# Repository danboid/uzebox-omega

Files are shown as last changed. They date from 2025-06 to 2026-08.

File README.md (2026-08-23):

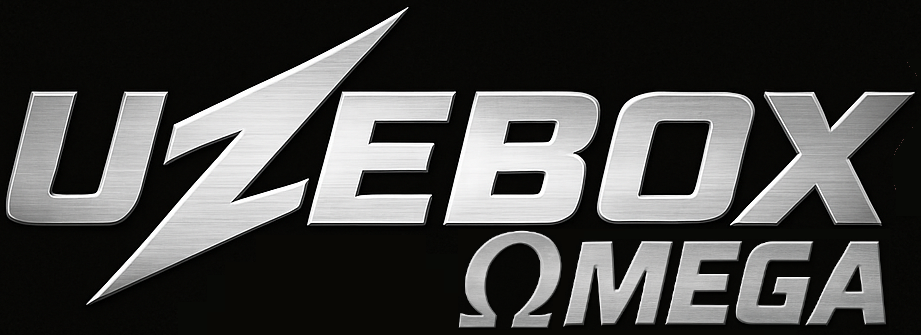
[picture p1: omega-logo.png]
Uzebox Omega logo


The Uzebox Omega is a modified version of the Uzebox open source games console that fits into the official Uzebox case and supports RGB SCART without the need for the expensive AD725 video chip.

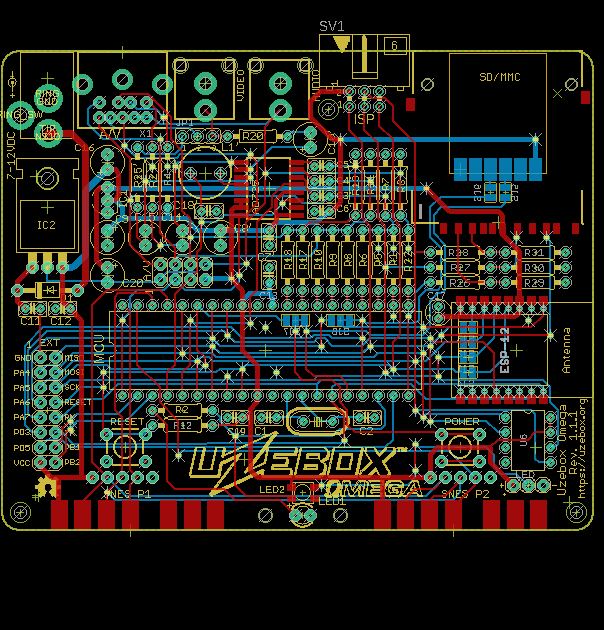
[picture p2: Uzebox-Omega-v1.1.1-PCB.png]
Uzebox Omega PCB


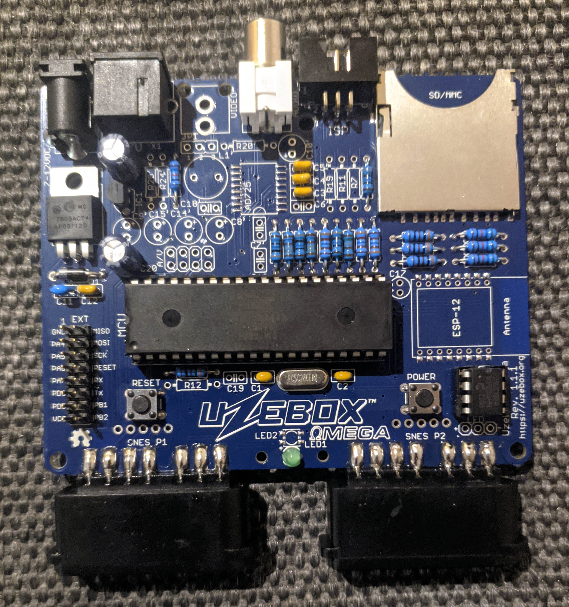
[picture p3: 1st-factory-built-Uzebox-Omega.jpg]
A PCBWay-built Uzebox Omega photo


## What is the same
* General schematic and functions inherited from the Uzebox v1.3.3.
* Mechanical dimensions. All buttons, connectors, holes, etc. are in the same place, so you can use the original case.

## New features
* SCART RGB support. Because space is too limited for the giant SCART connector, we use a Sega Mega Drive 2 compatible 9 pin Mini DIN connector and cables.

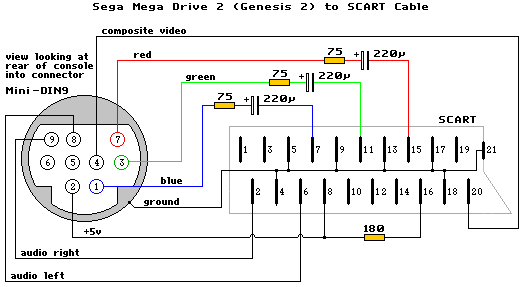
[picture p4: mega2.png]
Mini Din 9 pinout


* The AD725 chip and its surrounding parts are optional now. If you don't populate them RGB video works but you cannot use the composite video RCA jack.
* Optional footprint for an USB to serial module on the bottom side below the SD card socket. You can use this as a power supply connector to power your Uzebox from a USB wall plug. Also you can use it for debug messages, it is connected to the second UART of the AVR CPU. This leads to some small incompatibilities, so you have to activate it by a couple of solder jumpers on the bottom side. See instructions below.
* You can use an WS2812 "Neopixel" LED instead of the normal LED. There is no Uzebox kernel software for this yet. It uses the same pin as the original LED. A connector for adding more WS2812 LEDs is present so maybe you can create a colourful Uzebox sign in the top of your case?
* Added mounting holes for the lightpipe. You can screw or tie it to the board instead of glueing.
* I overworked all the traces to use a cleaner layout.
* The ESP12 WiFi chip can be connected to the CPU's SPI and reset lines. With this it should be possible to flash the AVR MCU via WiFi but we would need a custom Uzenet/ESP8266 firmware to enable this.

## SVideo adapter
The SVideo signals are routed to unused pins 5 (LUMA) and 6 (CHROMA) of the mini DIN socket so it should be possible to create a 9 pin mini DIN to SVideo adapter or cable.
 
## Instructions for using the ESP's SPI connection
The ESP's SPI pins GPIO12, 13 and 14 can be connected to the SPI lines of the AVR CPU so you have a very fast communication line between the two CPUs. GPIO16 can also be connected to the reset of the AVR. It should be possible to flash the AVR from the ESP with this. Four solder jumpers on the bottom of the PCB under the ESP would need to be bridged to enable this.

## Instructions for using the USB to serial module
WARNING: You have to leave out the 5V regulator if you want to use USB as power source!!!

The module has to be soldered to the bottom side of the PCB under the SD card socket. Because we cannot use holes there as they would conflict with the SD card, you have to solder the module directly onto the pads, or solder some angled pin hedaers onto the pad and put the module onto these. This method is perferred because it gives you a bit of distance between the SD card and the USB socket.

There are two solder jumpers near the module. They are open by default. So the module is connected to nothing, only to 5V for power supply.
If you close these jumpers the serial lines of the module will be connected to the second serial port of the AVR CPU. Because these are used by the standard Uzebox power button and ESP_RST pin there are two solder jumper which may connect these to PA5 and PA6 instead. This would need a software modification for software that uses the power button or the ESP_RST pin.

These jumpers are connected by a small wire in compatibility position. Without cutting these lines everything is like the original Uzebox.

## Instructions for WS2812 LED
If you want a colourful Neopixel LED instead of the normal one, just solder a WS2812 mini LED instead of the normal one. You can also skip the LEDs resistor then. There is a 3-pin connector at the right side of the PCB to connect more LEDs but don't overload the power supply!
Keep in mind that controlling such LEDs requires precise timing so it might be tricky to control such LEDs during video output.

## To find out more, please check out the project's sites:
* [Uzebox Omega PCBWay Shared Project](https://www.pcbway.com/project/shareproject/Uzebox_Omega_games_console_77d0d74a.html): Buy a pre-assembled Uzebox Omega from PCBWay.
* [Uzebox Omega Assembly Guide](https://github.com/danboid/uzebox-omega/blob/main/schematics/Uzebox-Omega/V1.1.1/Uzebox-Omega-V1.1.1-assembly-guide.md): How to build a Uzebox Omega. [PDF version for printing.](https://github.com/danboid/uzebox-omega/blob/main/schematics/Uzebox-Omega/V1.1.1/Uzebox-Omega-V1.1.1-assembly-guide.pdf)
* [Uzebox Omega Wiki page](https://uzebox.org/wiki/Omega): Uzebox Omega wiki page including build instructions, revision history etc.
* [Getting started](https://uzebox.org/wiki/Getting_Started_on_the_Uzebox): How to install the toolchains, IDEs and build the codebase. Then move on to tutorials and the rest of the documentation.  
* [Main website](https://uzebox.org): The main hub with news, links, downloads and more.
* [Forums](https://uzebox.org/forums): Share your new game and discuss everything Uzebox.
* [Wiki](https://uzebox.org/wiki): All of the Uzebox project's documentation.

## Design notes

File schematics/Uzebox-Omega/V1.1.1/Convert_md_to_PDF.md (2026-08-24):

# Converting markdown (.md) to PDF

I found that the markdown version of the assembly guide did not print well under most browsers.

I converted the markdown assembly guide into a PDF under Debian using these commands:

```
sudo apt install pandoc weasyprint
cd uzebox-omega/schematics/Uzebox-Omega/V1.1.1
pandoc Uzebox-Omega-V1.1.1-assembly-guide.md -o Uzebox-Omega-V1.1.1-assembly-guide.pdf --pdf-engine=weasyprint --css=style.css
```

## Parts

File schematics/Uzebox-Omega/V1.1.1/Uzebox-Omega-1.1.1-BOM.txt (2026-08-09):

Uzebox Omega v1.1.1 BOM - based upon the BOM of Uzebox v1.3.3. Last updated 9th August 2026.

Parts sourced from Digikey. Farnell equivalent order codes are listed in square brackets.

-----------------------------------------------------------------------------------------

1   2092-KMDGX-9S-BS-1-ND       CONN RCPT FMALE MINI DIN 9P SLDR    (X1) [152392] or use MDC-209

1   CP-1420-ND                  CONN RCA JACK R/A WHITE PCB         (AUDIO) [1280699] or [4066359] - Farnell only sell audio jacks for Omega v1.2+

1   CP-002A-ND                  CONN POWER JACK 2.1MM               (U5) [3498419] or [2839850]

1   2057-BHR-06-HUA-ND          CONN HEADER R/A 6POS 2.54MM         (ISP) [2751306]

1   10129381-916001BLF-ND       CONN HEADER VERT 16POS 2.54MM       (EXT) [1593445]

1   3M5471-ND                   SOCKET IC OPEN FRAME 40POS .6"      [2453477]

2   TS02-66-43-BK-100-LCR-D     6MM LIGHT TOUCH SWITCH 100GF        (POWER,RESET) [2543101]

1   732-3816-1-ND               CONN SD CARD PUSH-PUSH R/A SMD      (SD/MMC) [2081359]

2   399-9718-ND                 CAP CER 18PF 100V 5% NP0 RADIAL     (C1,C2) [3001200] or [2332948]

2   399-ESK105M350AE3AA-ND      CAP ELECT 1UF 50V VR RADIAL         (C16,C20) [9451358]

4   478-3192-ND                 CAP CER .10UF 50V 20% RADIAL        (C3,C4,C5,C12) [3289388]

1   478-5733-ND                 CAP CER .33UF 50V Z5U 20% RADIAL    (C11) [4143699]

4   301XBK-ND                   RES 301 OHM 1/4W 1% METAL FILM      (R2,R26,R27,R28) [9467149] or [1083195]

4   562XBK-ND                   RES 562 OHM 1/4W 1% METAL FILM      (R29,R30,R31,video fix) [4141008] or [9502386]

3   3.16KXBK-ND                 RES 3.16K OHM 1/4W 1% METAL FILM    (R1,R8,R22) [1083307]

1   13-MFR-25FTE52-180RCT-ND    RES 180 OHM 1% 1/4W 1% METAL FILM   (R4) [1083165] *

3   1.58KXBK-ND                 RES 1.58K OHM 1/4W 1% METAL FILM    (R5,R9,R17) [9465375] or [9500928]

4   806XBK-ND                   RES 806 OHM 1/4W 1% METAL FILM      (R3,R6,R10,R18) [9470204] or [1751433]

1   ATMEGA644A-PU               IC MCU AVR 64K FLASH 40-DIP         (MCU) [1288340]

1   MC7805ACTGOS-ND             IC REG LINEAR 5V 1A TO220           (IC2) [9664505]

1   641-1310-1-ND               1N4001 DIODE RECTIFIER 1A 50V DO-41 (D1) [2822512]

1   XC1728-ND                   CRYSTAL 28.63636MHZ 18PF TH         (XTAL) [1842243]

1   MCP1700-3302E/TO-ND         IC LDO REG 250MA 3.3V TO-92-3       (IC1) [1331485] or [1296588]

1   67-1056-ND                  LED 3MM SHORT LENS GREEN DIFF       (LED1) [L034XGT] or [3780477] for a brighter LED

--Optional parts for Uzebox Omega composite or svideo (via adapter) video output (UNTESTED)--

1   AD725ARZ-ND                 IC ENCODER RGB TO NTSC 16-SOIC      (U2) See alternative source below.

1   CP-1421-ND                  CONN RCA JACK R/A YELLOW PCB        (VIDEO)

2   478-3192-ND                 CAP CER .10UF 50V 20% RADIAL        (C6,C7)

2   P19607CT-ND                 CAP ALUM 10UF 20% 50V RADIAL        (C8,C9)

1   493-1041-ND                 CAP 220UF 16V ELECT VR RADIAL       (C10)

1   P19607CT-ND                 CAP ALUM 10UF 20% 50V RADIAL        (C13) [2841905]

2   493-1041-ND                 CAP 220UF 16V ELECT VR RADIAL       (C14,C15) [8767149]

3   75.0XBK-ND                  RES 75.0 OHM 1/4W 1% METAL FILM     (R20,R24,R25) [1127008]

1   399-9718-ND                 CAP CER 18PF 100V 5% NP0 RADIAL     (C18)

1   RLB0914-680KL-ND            INDUCTOR 68UH 10% RADIAL            (L1)

1   SAM1112-03-ND               CONN HEADER VERT 3POS 2.54MM        (JP1) [1593412]

1   S9337-ND                    CONN JUMPER SHORTING .100" GOLD     (JP1) [2834673]

--Optional SPI RAM module--     Required by UzeboxPC, UzeMOD etc.

1   23LC1024-I/P-ND             IC SRAM 1MBIT SPI/QUAD 8DIP         (U6, not available from Farnell)

1   AE9986-ND                   CONN IC DIP SOCKET 8POS TIN         (U6) [2678577]

--Optional Uzenet Interface--   Requires the SPI RAM module components

1   https://vi.aliexpress.com/item/32264795859.html                 ESP-12F WiFi Module. Not available from Farnell. DigiKey uses non compat. firmware

1   445-8417-ND                 CAP CER 1UF 16V X7R RADIAL          (C17)

2   2057-2RS1-08-G-ND           RECEPTACLE STRIP 8P 2.0MM PITCH     (ESP12)

2   952-2278-ND                 CONN HEADER VERT 8POS 2MM           (To solder onto ESP-12F WiFi module)

--Optional Uzebox parts--

1   993-PYA15T120125-ND         AC/DC WALL MOUNT ADAPTER 12V 15W      12V 15 W AC/DC External Wall Mount Adapter Multi-Blade (Included) Input. US/EU/UK/AU plugs.

1   102-6551-ND                 AC/DC WALL MOUNT ADAPTER 12V 6W       12V 6 W AC/DC External Wall Mount PSU. Includes North American, Europe, UK, Australia and China plugs.

1   1470-VFR05US090-JA-ND       9V 5W AC/DC External Wall Mount (Class II) Adapter Multi-blade (plugs) included - US, UK, EU and AU.

1   364-1253-ND                 9V 6W 600ma DC wall mount, Positive Center, Barrel Plug, 2.1mm I.D. x 5.5mm O.D. x 9.5mm, North American plug only.

1   3373676                     MicroSD Memory Card Connector       Can only be used instead of the full sized SD on Uzebox Omega 1.3+.

4   SJ5303-7-ND                 BUMPON HEMISPHERE .44X.20 CLEAR

Parts sourced elsewhere

------------------------------------------------------------------------------------

1   PRT-12769               SD/MMC Socket (Alternate source)        (SD/MMC)                        https://www.sparkfun.com/products/12769

1   AD725ARZ                IC ENCODER RGB TO NTSC 16-SOIC (alternate, much cheaper source) (U2)    https://vi.aliexpress.com/item/33022801012.html . AD725 is not recommended for the Omega.

2   SNES connectors         (Straight pin version) AliExpress.com   (SNESP1,SNESP2)                 Prefered, 180 degree model: https://www.aliexpress.com/item/32879502446.html , alternative 90 degree connector: https://vi.aliexpress.com/item/32838396935.html

1   PCB                     JLCPCB.com PCB Manufacturing service                                    See the following on how to order: https://uzebox.org/forums/viewtopic.php?p=33217#p33217 or use PCBWay.com

2   SNES controllers        SNES/SFC Controller Classic Wired Gamepad                               https://vi.aliexpress.com/item/1005007109314003.html

1   SCART AV cable          RGB Scart cable for Sega Mega Drive 2                                   https://vi.aliexpress.com/item/1005007039881314.html , see https://uzebox.org/wiki/Uzebox_SCART_Interface#SCART_cables for more

1   AVR programmer          USBASP USBISP AVR Programmer                                            https://www.aliexpress.com/item/32670511994.html , be sure to buy one with 10 pin to 6 pin cable adapter

* For R4, this BOM currently uses a 180 Ohm resistor from Digikey but a 162 Ohm resistor from Farnell, because Farnell UK currently only sell 180 Ohm resistors in batches of 10 or more. Any resistor from 150 to around 220 Ohms should suffice for R4.

https://uzebox.org/wiki/Omega

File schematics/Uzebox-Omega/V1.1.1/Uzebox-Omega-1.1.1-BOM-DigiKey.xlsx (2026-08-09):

Digi-Key Part Number | Quantity | Uzebox Omega v1.1.1 Digi-Key BOM. Last updated 9th August 2026.
2092-KMDGX-9S-BS-1-ND | 1 | CONN RCPT FMALE MINI DIN 9P SLDR (X1)
CP-002A-ND | 1 | CONN POWER JACK 2.1MM (7-12VDC)
CP-1420-ND | 1 | CONN RCA JACK R/A WHITE PCB (AUDIO)
2057-BHR-06-HUA-ND | 1 | CONN HEADER R/A 6POS 2.54MM (ISP) or 75867-231LF-ND
10129381-916001BLF-ND | 1 | CONN HEADER VERT 16POS 2.54MM (EXT)
3M5471-ND | 1 | SOCKET IC OPEN FRAME 40POS .6" (MCU)
TS02-66-43-BK-100-LCR-D | 2 | 6MM LIGHT TOUCH SWITCH 100GF (POWER,RESET)
732-3816-1-ND | 1 | CONN SD CARD PUSH-PUSH R/A SMD (SD/MMC)
399-9718-ND | 2 | CAP CER 18PF 100V 5% NP0 RADIAL (C1,C2)
399-ESK105M350AE3AA-ND | 2 | CAP ALUM 1UF 20% 350V RADIAL TH (C16,C20)
478-3192-ND | 4 | CAP CER .10UF 50V 20% RADIAL (C3,C4,C5,C12)
478-5733-ND | 1 | CAP CER .33UF 50V Z5U 20% RADIAL (C11)
301XBK-ND | 4 | RES 301 OHM 1/4W 1% METAL FILM (R2,R26,R27,R28)
562XBK-ND | 4 | RES 562 OHM 1/4W 1% METAL FILM (R29,R30,R31) and X1 video fix
3.16KXBK-ND | 3 | RES 3.16K OHM 1/4W 1% METAL FILM (R1,R8,R22)
13-MFR-25FBF52-162R-ND | 1 | RES 162 OHM 1% 1/4W AXIAL (R4)
1.58KXBK-ND | 3 | RES 1.58K OHM 1/4W 1% METAL FILM (R5,R9,R17)
806XBK-ND | 4 | RES 806 OHM 1/4W 1% METAL FILM (R3,R6,R10,R18)
ATMEGA644A-PU | 1 | IC MCU AVR 64K FLASH 40-DIP (MCU)
MC7805ACTGOS-ND | 1 | IC REG LINEAR 5V 1A TO220 (IC2)
641-1310-1-ND | 1 | 1N4001 DIODE RECTIFIER 1A 50V DO-41 (D1)
XC1728-ND | 1 | CRYSTAL 28.63636MHZ 18PF TH (XTAL)
MCP1700-3302E/TO-ND | 1 | IC LDO REG 250MA 3.3V TO-92-3 (IC1)
67-1056-ND | 1 | LED 3MM SHORT LENS GREEN DIFF (LED1)
AE9986-ND | 1 | CONN IC DIP SOCKET 8POS TIN (U6) - optional but recommended
23LC1024-I/P-ND | 1 | IC SRAM 1MBIT SPI/QUAD 8DIP (U6) - optional but recommended

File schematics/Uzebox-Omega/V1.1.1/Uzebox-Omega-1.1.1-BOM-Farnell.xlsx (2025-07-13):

Part Number | Quantity | Uzebox Omega v1.1.1 Farnell components BOM. Last updated 12th July 2025.
152392 | 1 | 9-pole Mini DIN Audio/Video Socket
3498419 | 1 | DC Power Connector, Receptacle, 2.1 mm, PCB Mount, Solder or use 2839850
2751306 | 1 | Pin Header, Right Angle, Wire-to-Board, 2.54 mm, 2 Rows, 6 Contacts, Through Hole Right Angle or 2215288
1593445 | 1 | MULTICOMP PRO 2213S-16GPin Header, Board-to-Board, 2.54 mm, 2 Rows, 16 Contacts, Through Hole Straight, 2213S
2453477 | 1 | IC & Component Socket, 40 Contacts, DIP Socket, 2.54 mm, 15.24 mm, Phosphor Bronze
2543101 | 2 | Tactile Switch, MCDTS-6, Top Actuated, Through Hole, Round Button, 160 gf, 50mA at 12VDC
2081359 | 1 | Memory Card Connector, SD, Push-Push, 9 Contacts, Copper, Gold Plated Contacts, WR-CRD
3001200 | 5 | Multilayer Ceramic Capacitor, 18 pF, 100 V, ± 5%, Radial Leaded, C0G / NP0, 2.5 mm. Only 2x needed, 5x min sale or use 2332948
9451358 | 2 | MULTICOMP PRO MCGPR50V105M5X11Electrolytic Capacitor, 1 µF, 50 V, ± 20%, Radial Leaded, 2000 hours @ 85°C, Polar
3289388 | 4 | Multilayer Ceramic Capacitor, 0.1 µF, 50 V, ± 10%, Radial Leaded, X7R, 2.5 mm
4143699 | 1 | Multilayer Ceramic Capacitor, 0.33 µF, 50 V, ± 10%, PC Pin, X7R, 2.5 mm
9467149 | 10 | Through Hole Resistor, 301 ohm, MRS25 Series, 600 mW, ± 1%, Axial Leaded, 350 V. Only 4x needed, 10x min sale or use 1083195
4141008 | 10 | Through Hole Resistor, 562 ohm, MBB0207 Series, 600 mW, ± 1%, Axial Leaded, 350 V. Only 3x needed, 10x min sale or use 9502386
1083307 | 3 | Through Hole Resistor, 3.16 kohm, R, 250 mW, ± 0.1%, Axial Leaded, 500 V
1083165 | 1 | Through Hole Resistor, 162 ohm, R, 250 mW, ± 0.1%, Axial Leaded, 500 V
9465375 | 10 | Through Hole Resistor, 1.58 kohm, MRS25, 600 mW, ± 1%, Axial Leaded, 350 V. Only 3x needed, 10x min sale or use 9500928 .
9470204 | 10 | Through Hole Resistor, 806 ohm, MRS25, 600 mW, ± 1%, Axial Leaded, 350 V. Only 4x needed or use 1751433
1288340 | 1 | 8 Bit MCU, Low Power High Performance, AVR ATmega Family ATmega64 Series Microcontrollers, AVR
9664505 | 1 | Linear Voltage Regulator, 7805, Fixed, Positive, 10V To 35V In, 5V And 1A Out, TO-220-3
2822512 | 5 | Standard Recovery Diode, 50 V, 1 A, Single, 1.1 V, 30 A. Only 1x needed, 5x min sale
1842243 | 1 | Crystal, 28.63636 MHz, Through Hole, 11.5mm x 5mm, 10 ppm, 18 pF, 10 ppm, 9B
1331485 | 1 | MICROCHIP MCP1702-3302E/TO, Fixed LDO Voltage Regulator, 2.7V to 13.2V, 525mV Dropout, 3.3Vout, 250mAout, TO-92-3 or use 1296588
L034XGT | 5 | MULTICOMP PRO L034XGTLED, AlInGaP, Green, Through Hole, T-1 (3mm), 20 mA, 2.1 V, 570 nm. Only 1x needed, 5x minimum sale or use 3780477 if you want a brighter power LED.

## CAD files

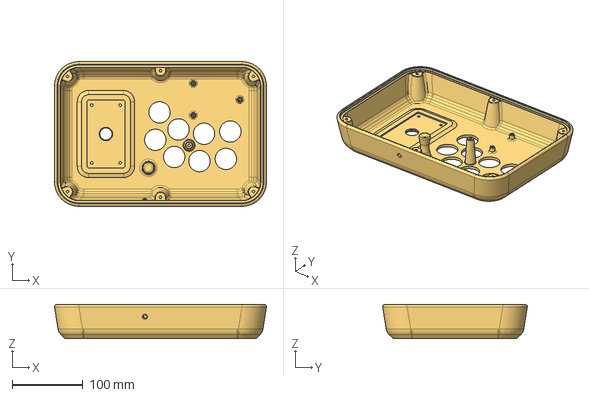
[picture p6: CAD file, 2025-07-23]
cad/Enclosures/fightstick/Fight Stick Uzebox Edition v7.step
299.2 x 204.2 x 48.0 mm

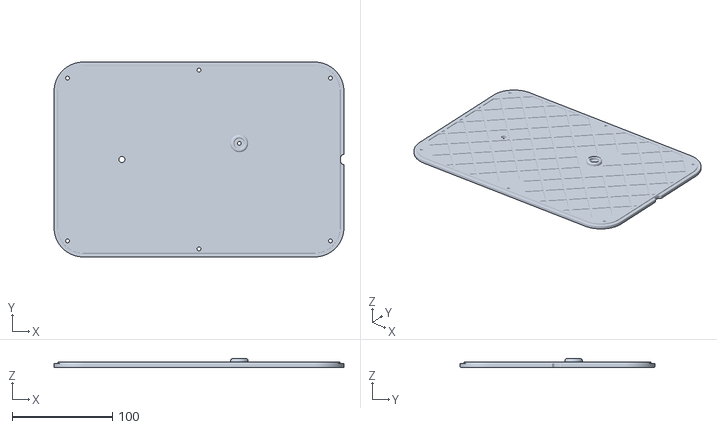
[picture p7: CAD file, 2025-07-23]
cad/Enclosures/fightstick/Fightstick Bottom V3 30mm.stl
289.6 x 194.6 x 8.70

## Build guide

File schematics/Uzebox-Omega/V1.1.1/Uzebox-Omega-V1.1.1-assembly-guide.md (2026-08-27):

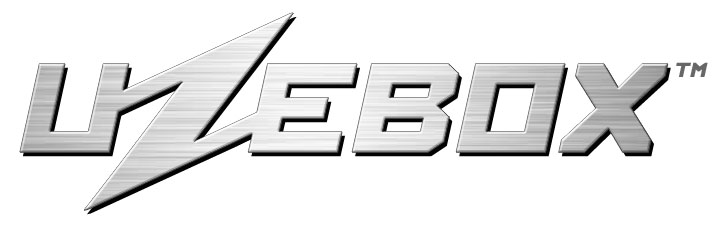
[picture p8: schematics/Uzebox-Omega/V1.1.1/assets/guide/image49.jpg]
Uzebox V5.0


# Uzebox Omega assembly guide
For Uzebox Omega Revision V1.1 to v1.4

> [!NOTE]  
> This assembly guide was written with consideration of the electronics beginner who only has a minimal set of tools. Some of the methods described in this guide are makeshift solutions for those without more professional tooling. Use the method which works best for you.

## Revision History
| Version | Date | Author | Description |
| :---- | :---- | :---- | :---- |
| 0 | 01-Nov-2012 | A.Bourque | Initial release |
| 1 | 6-Nov-2012 | A.Bourque | Minor corrections |
| 2 | 28-Jan-2014 | A.Bourque | Minor changes |
| 3 | 27-Jan-2015 | A.Bourque | Added replacement parts for EXT header and SD card socket |
| 4 | 21-Feb-2015 | A.Bourque | Added preliminary troubleshooting section |
| 5 | 26-Nov-2015 | A.Bourque | Minor improvements |
| 6 | 1-Feb-2016 | A.Bourque | Added note regarding power button |
| 7 | 15-Nov-2016 | A.Bourque | Added notes for PCB rev 1.3.1 and references to the Uzenet interface. |
| 8 | 13-Aug-2024 | A.Bourque | Ported the assembly guide to GitHub and added minor improvements. |
| 9 | 28-Aug-2024 | D.MacDonald | Several additions and improvements. |
| 10 | 17-Sep-2024 | D.MacDonald | Add solder flux, a video cable and a SNES controller to the "Other parts required" table. |
| 11 | 11-Jul-2025 | D.MacDonald | Started work on modifying the Uzebox assembly guide for the Uzebox Omega. |

## Parts list verification
> [!IMPORTANT]  
> Ensure you have all the required parts before starting, 

<!--
> [!TIP] 
> Click on the images for a bigger view.
-->
| Component Image | Schematic Reference | Description |
| ----- | ----- | ----- |
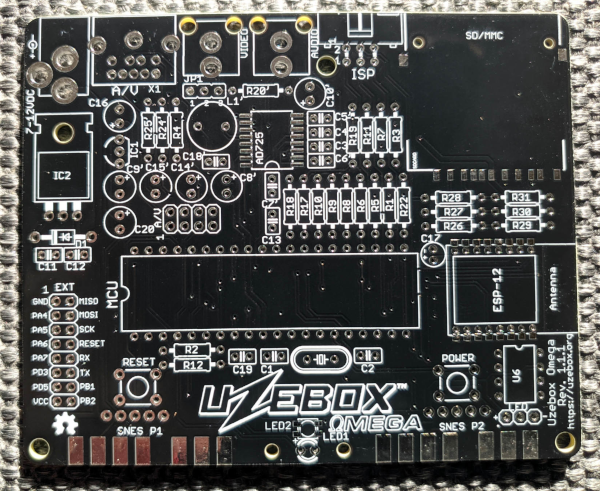
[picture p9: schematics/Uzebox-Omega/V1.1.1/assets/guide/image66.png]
Uzebox Omega PCB
|  | N/A 		 | Uzebox Omega printed circuit board (PCB) 		 |
| Power Jack | N/A 		 | DC power jack 		 |		 		 |
| Audio RCA Jack | AUDIO 		 | Audio output RCA jack (Red or white) - optional		 |
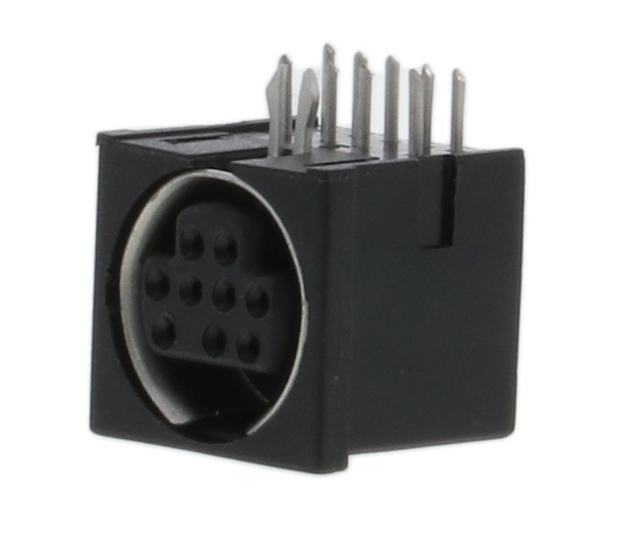
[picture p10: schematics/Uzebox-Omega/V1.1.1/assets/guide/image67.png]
Mini DIN RGB SCART AV output
|  | X1 		 | A female, 9 pin mini DIN socket 			 		 |
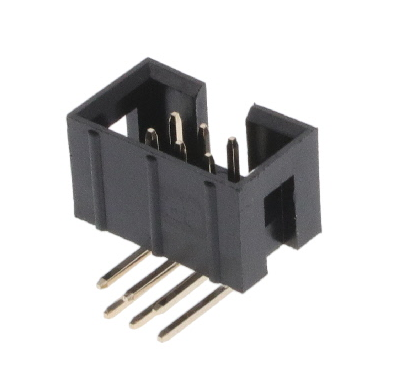
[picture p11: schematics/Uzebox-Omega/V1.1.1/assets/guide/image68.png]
Right-angled ISP programming port
|  | ISP 		 | Right-angled Atmega644 programming ports are preferred over vertical ones. 					 		 |
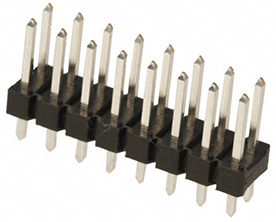
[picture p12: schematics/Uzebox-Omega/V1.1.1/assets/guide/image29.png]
Extension Header
|  | EXT 		 | Extension port header - optional		 |
| DIP-40 Socket  | MCU 	 | DIP-40 socket for the Atmega644 							 |
| Tactile Switches  | POWER / RESET  | Tactile 	switches (x2) 				 |
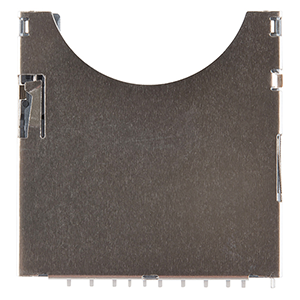
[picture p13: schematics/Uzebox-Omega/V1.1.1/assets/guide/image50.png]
SD Card Socket
|   | SD/MMC 		 | Secure Digital memory card socket. One of the two possible models has a soldering wing on the right side only. |
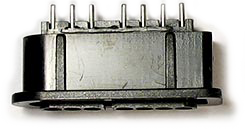
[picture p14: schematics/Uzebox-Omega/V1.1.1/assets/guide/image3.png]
SNES Connector
|   | SNESP1 SNESP2 	 		 | SNES gamepad connectors (x2)			 		 |
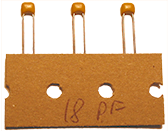
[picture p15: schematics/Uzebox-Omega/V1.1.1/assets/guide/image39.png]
18pF Capacitors
|   | C1,C2 		 | 18pF ceramic capacitors		 		 |
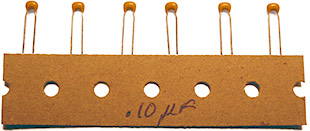
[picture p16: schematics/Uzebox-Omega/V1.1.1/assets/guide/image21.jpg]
100nF Capacitors
|   | C3,C4,C5, C12 	 | .10uF (100nF) ceramic capacitors 	 |
| .33uF Capactitor  | C11 | .33uF (330nF) ceramic capacitor 	 |		 |		 |
| 301 Ohm Resistor  | R2,R26, R27,R28  | Resistor 301Ω 1% (Orange, black, brown, black, brown) 		 |
| 560 Ohm Resistor  | R29,R30, R31, video fix | Resistor 562Ω 1% (Green, blue, red, black, brown) 	 |
| 806 Ohm Resistor  | R3,R6,R10,R18 		 | Resistor 806Ω 1% (Gray, black, blue, black, brown)	 |
| 1.58K Ohm Resistor  | R5,R9,R17	 | Resistor 1.58KΩ 1% (Brown, green, gray, brown, brown)  |
| 3.16K Ohm Resitor  | R1,R8,R22	 | Resistor 3.16KΩ 1% (Orange, brown, blue, brown, brown) 	 |
| Atmega644 Microcontroller  | MCU 	 | ATmega644 microcontroller 			 		 |
| Crystal  | XTAL | 28.63636Mhz crystal  |			 		 |
| 3.3V Voltage Regulator  | IC1 	 | 3.3V voltage regulator  |
| 5V Voltage Regulator  | IC2 	 | 5.0V voltage regulator 		 |
| Rectifier Diode  | D1  | Rectifier diode 			 |
| LED  | LED1	 | Power	LED  |
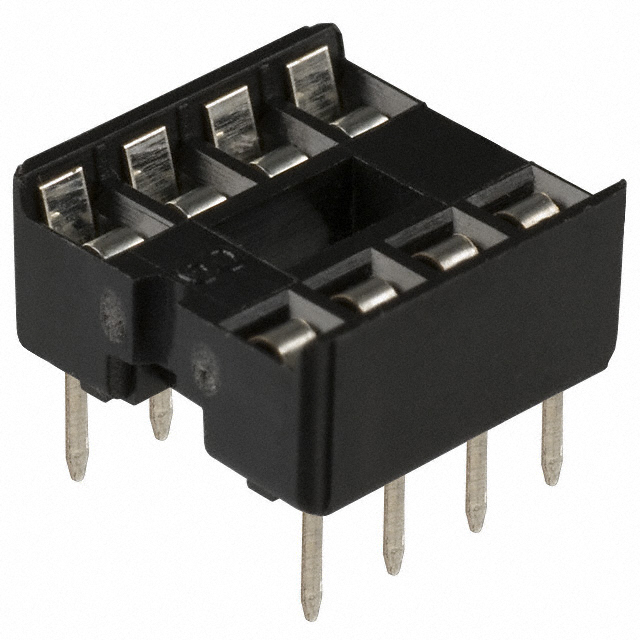
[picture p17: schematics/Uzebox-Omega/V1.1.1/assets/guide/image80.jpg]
DIP-8 Socket
|   | U6	 | SPI SRAM socket - optional |
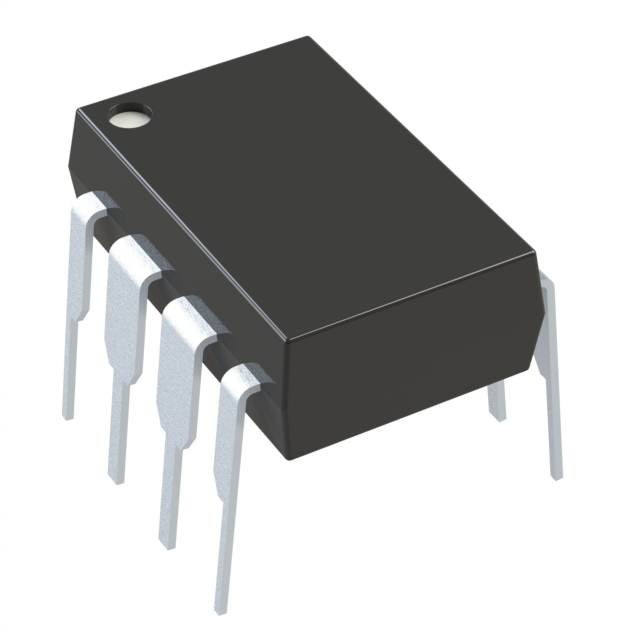
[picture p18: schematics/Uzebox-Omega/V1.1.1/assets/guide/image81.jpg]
1Mb SPI SRAM
|   | U6	 | 1Mb (128KB) SPI SRAM IC - optional |

## Tools required

To assemble this kit you will need the following tools:

| Tool | Description |
| :---: | ----- |
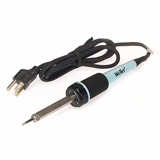
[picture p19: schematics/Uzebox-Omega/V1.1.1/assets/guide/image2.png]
Soldring Iron
|  | A basic soldering iron, 25W-40W. |
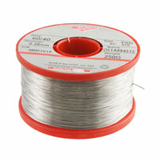
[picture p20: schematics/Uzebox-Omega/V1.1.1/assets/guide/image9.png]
Solder
|   | Solder, rosin core, 60/40 type. |
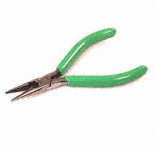
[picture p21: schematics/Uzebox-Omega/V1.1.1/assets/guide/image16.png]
Long Nose Plyers
|   | Long nose pliers. |
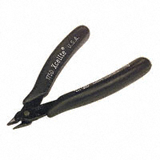
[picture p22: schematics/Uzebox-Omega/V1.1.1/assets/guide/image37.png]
Shear Cutters
|   | Regular cutters will do fine, but shear cutters will do a better job. |
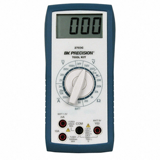
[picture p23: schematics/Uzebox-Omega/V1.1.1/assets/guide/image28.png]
|   | A basic multimeter is not essential but highly recommended for verifications and troubleshooting. |
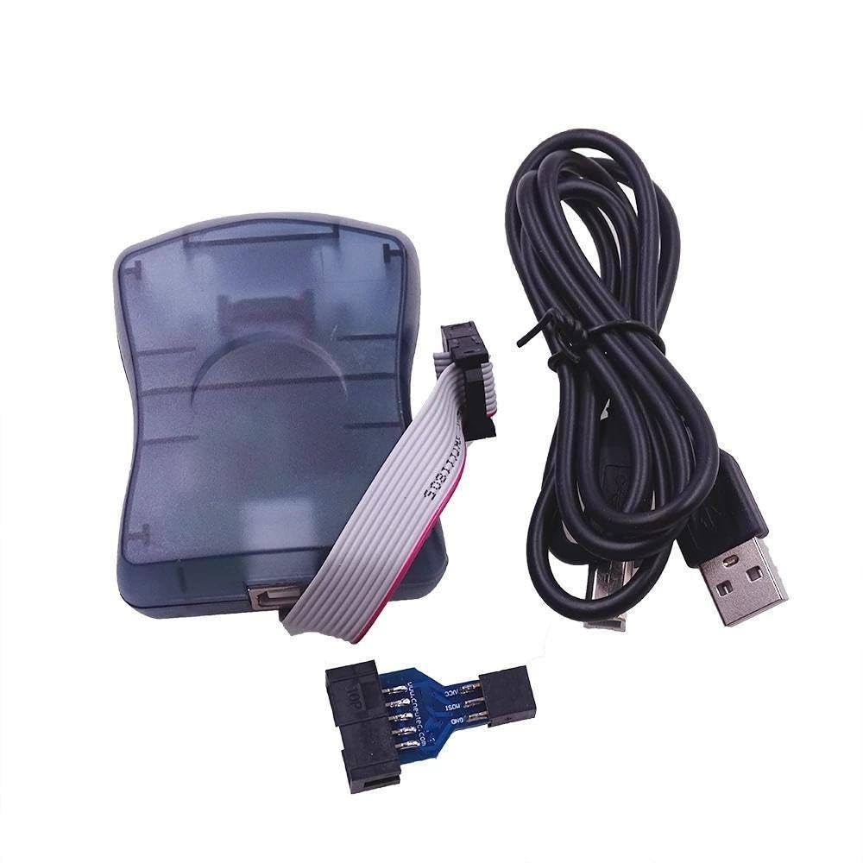
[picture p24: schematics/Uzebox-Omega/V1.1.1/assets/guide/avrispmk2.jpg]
AVRISpmk2
|   | An AVR ISP programmer. Required to flash the Atmega644 microcontroller. Alternately, you can flash the Atmega using [avrdude](https://uzebox.org/wiki/Avrdude) and the GPIO header of a Raspberry Pi or similar.|

## Other parts required

| Part | Description |
| :---: | ----- |
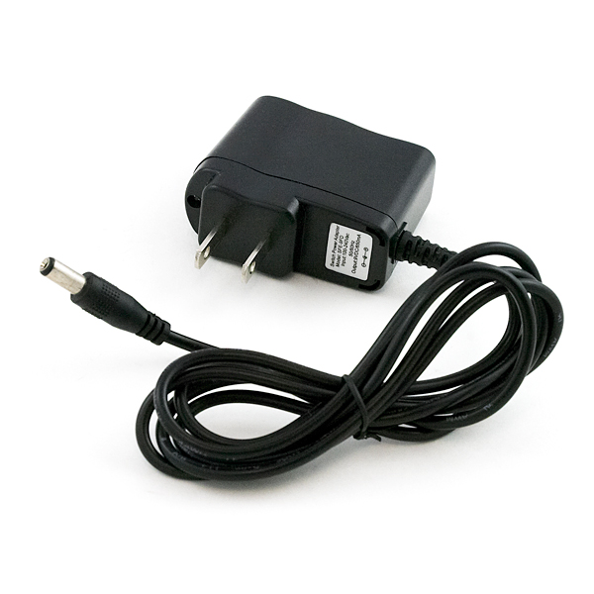
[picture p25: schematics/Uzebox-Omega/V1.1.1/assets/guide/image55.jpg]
Power supply
|   | A standard 7-12VDC barrel connector power supply with a center-positive, 5.5x2.1mm tip. See the Omega's text BOM for a few suitable DigiKey PSUs. |
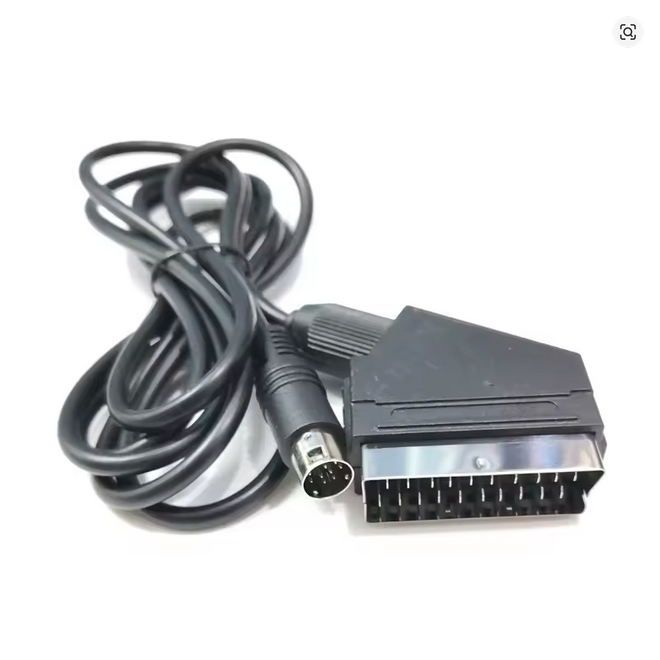
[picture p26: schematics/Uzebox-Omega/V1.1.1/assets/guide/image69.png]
Sega Mega Drive / Genesis 2 RGB SCART cable
|   | A Sega Mega Drive 2 / Sega Genesis 2 compatible 9 pin mini DIN to RGB SCART cable. [Shielded, CSYNC cables](https://uzebox.org/wiki/Uzebox_SCART_Interface#SCART_cables) are recommended for the best sound and video quality. |
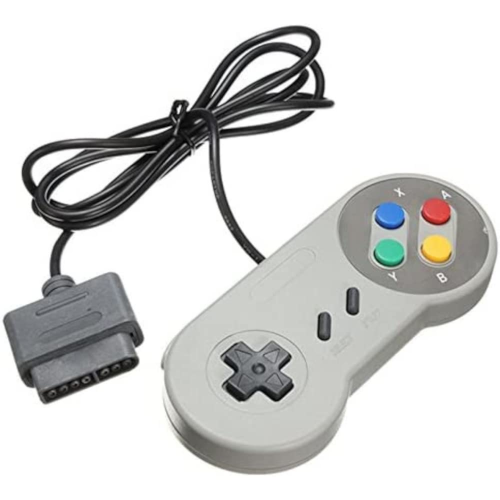
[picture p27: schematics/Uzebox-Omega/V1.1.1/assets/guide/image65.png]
SNES controller
|   | A [SNES controller.](https://uzebox.org/wiki/FAQ#Where_can_I_buy_Uzebox_compatible_controllers?) |
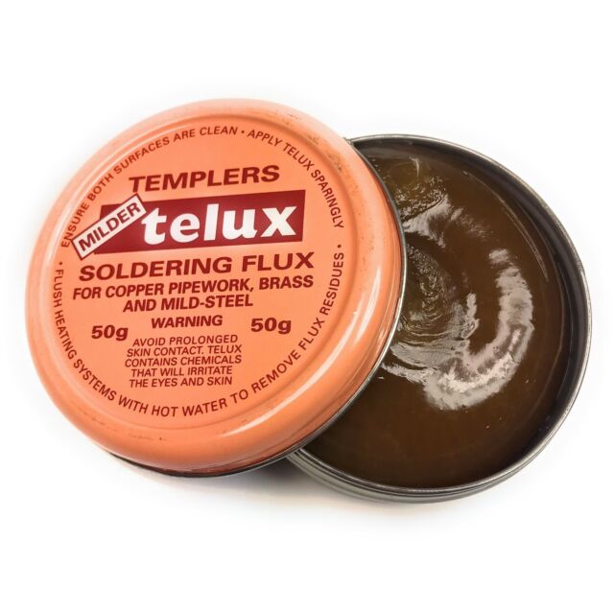
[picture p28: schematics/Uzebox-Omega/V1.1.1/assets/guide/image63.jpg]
Solder flux
|   | Solder flux. Not strictly required but flux makes it much easier to solder the SNES connectors and SD card socket.|

## Building the kit
### Assembling the power supply section

<table>
    <tr>
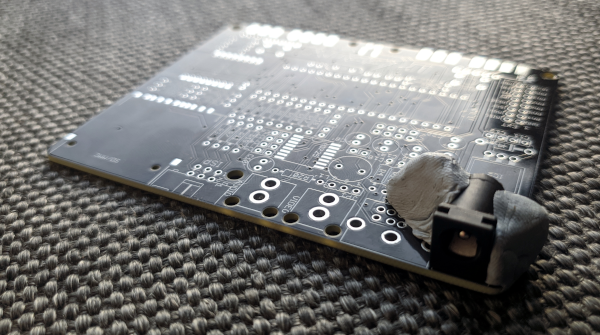
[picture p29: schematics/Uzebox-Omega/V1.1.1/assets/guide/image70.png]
        <td width="50%"></td>
        <td>If your power jack is too far out of alignment it can prevent you correctly inserting the mini DIN AV socket. I use Blu Tack or some other putty-like adhesive to keep the power jack correctly aligned whilst soldering it.</td>
    </tr>
    <tr>
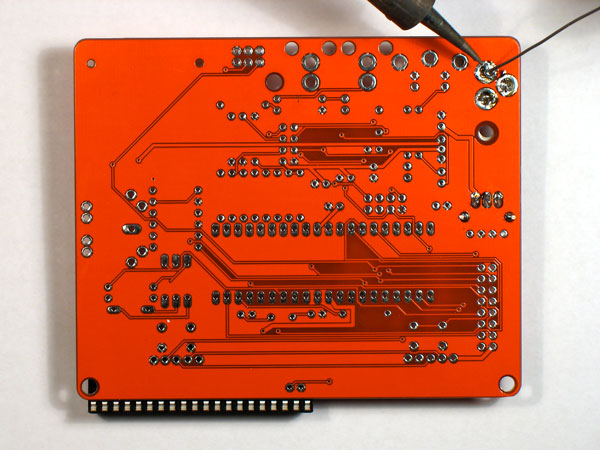
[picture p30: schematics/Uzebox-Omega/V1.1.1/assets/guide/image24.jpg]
        <td></td>
        <td>Insert the DC barrel jack. It is recommended that you start by soldering the power jack first. The main reason being it is quite easy to solder the power jack at an angle with the PCBs that use the circular power jack footprints instead of using slots, as used on later revisions of the Omega. The power jack can be tricky to desolder if you don't own a desoldering station/gun so if you mess up by not soldering the power jack on straight enough then you may as well start over with a new PCB if you don't own any desoldering tools.<br/><br/>Bend the pins on the soldering side to keep it held firmly in place. To ensure it's soldered flat, you can also put the 40 pin DIP socket underneath the PCB to level it up. Be sure to put plenty of solder on the three pins so that the jack is securely mounted.</td>
    </tr>
    <tr>
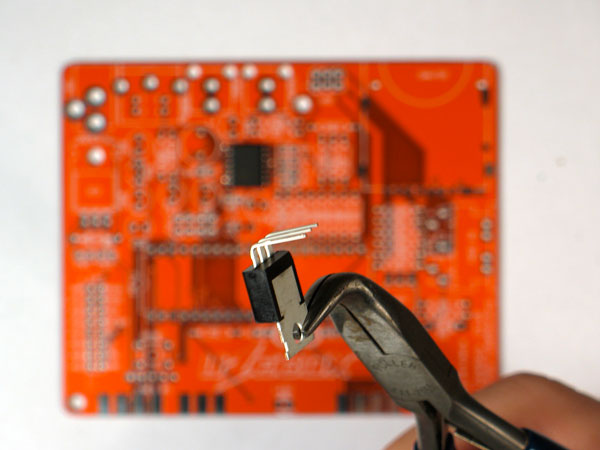
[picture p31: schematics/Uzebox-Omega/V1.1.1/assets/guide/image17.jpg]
        <td width="50%"></td>
        <td>Using pliers, bend the pins of <b>IC2</b>, the 5V voltage regulator, at a 90 degrees angle as pictured. Alternately, insert the legs into the PCB up to the notches then bend the top part until it is lying flat on the PCB. Whilst holding the regulator flat, use the edge of a ruler or maybe a file to bend the regulators legs flat against the PCB on the underside of the board.</td>
    </tr>
    <tr>
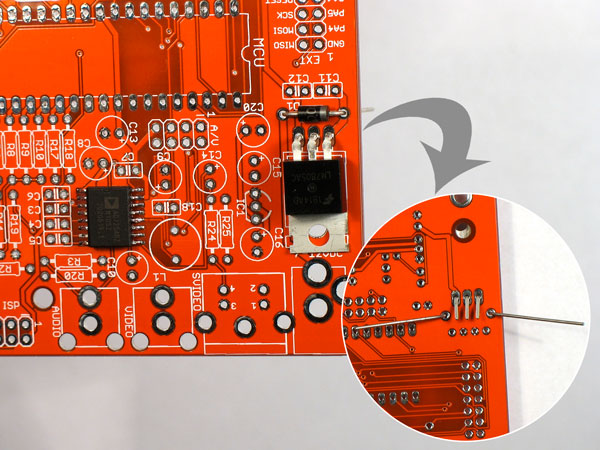
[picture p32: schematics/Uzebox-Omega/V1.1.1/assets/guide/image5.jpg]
        <td></td>
        <td>Mount <b>IC2</b> on the PCB along diode <b>D1</b>. Notice the diode has a white stripe on one end to indicate the direction of current. Ensure the band matches with the component’s drawing on the PCB. As with all future components you will solder, when inserting a component, bend its pins on the other side of the PCB so it holds in place.  Flip the PCB and solder all pins.</td>
    </tr>
    <tr>
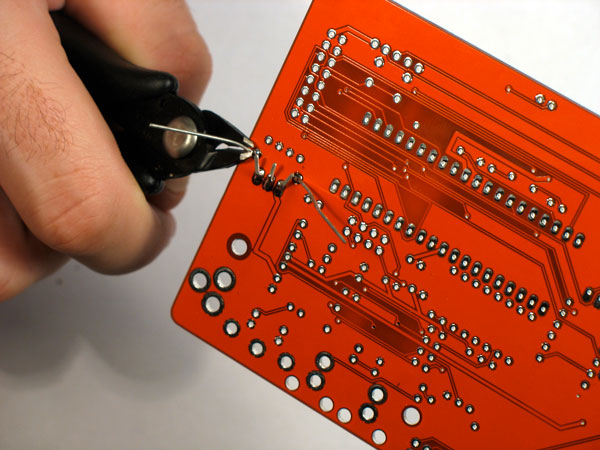
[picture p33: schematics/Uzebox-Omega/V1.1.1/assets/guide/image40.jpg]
        <td></td>
        <td>Using the cutters, cut the pins excess wire. It is recommended that you wear eye protection when using wire cutters. You should hold wires whilst cutting them to stop the wire bits flying into someones eye.</td>
    </tr>
    <tr>
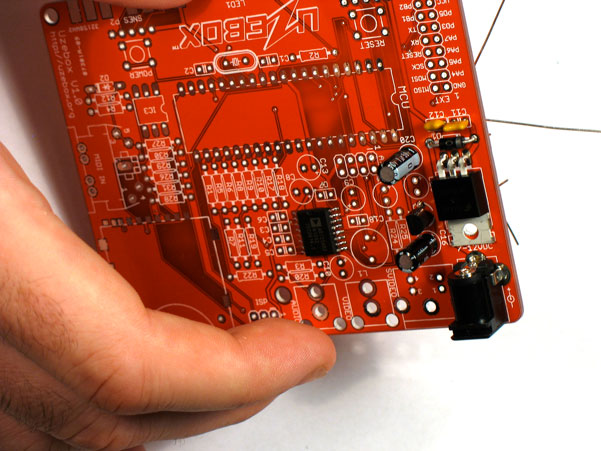
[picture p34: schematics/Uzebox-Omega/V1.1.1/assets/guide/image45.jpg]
        <td></td>
        <td>Add <b>C11</b> (.33uF), <b>C12</b> (100nF), <b>C16</b> (1uF), <b>C20</b> (1uF) and <b>IC1</b> (3.3v regulator). The electrolytic capacitors (the black or dark blue cans) have a polarity. The negative pin is marked with a white stripe and little minus signs on the side. Ensure the opposite pin (the longest one) inserts in the hole which has a little "+" next to it. Solder all pins and remove excess wire. That completes the power supply section.</td>
    </tr>
    <tr>
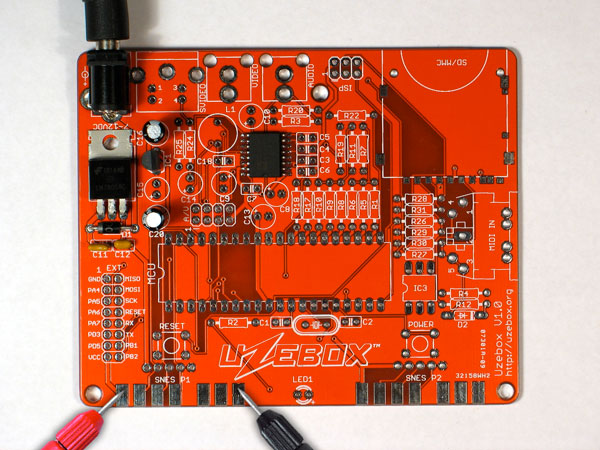
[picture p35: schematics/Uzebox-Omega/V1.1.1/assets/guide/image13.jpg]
        <td></td>
        <td>If you have a multimeter, let’s test what we have so far. Switch your multimeter to DC voltage measurement mode. Plug in the power supply and probe pin 1 and 7 on the P1 SNES connector footprint. If all goes well, you should measure around 5V. Unplug the power.<br/><br/>If you aren't getting around 5V, check your soldering. It's more likely to be a soldering issue than faulty components if you are new to soldering and the components are new. Heat up your soldering iron and touch up all of the solder joints made so far on the underside of the PCB then try another voltage measurement.<br/><br/>If you have a hot air gun you can try reflowing the joints. Heating the solder until you can see it start to melt without then using a solder sucker or wick to remove any of it can often fix substandard or faulty solder joints.</td>
    </tr>
</table>

### Assembling the microcontroller and sound section

<table>
    <tr>
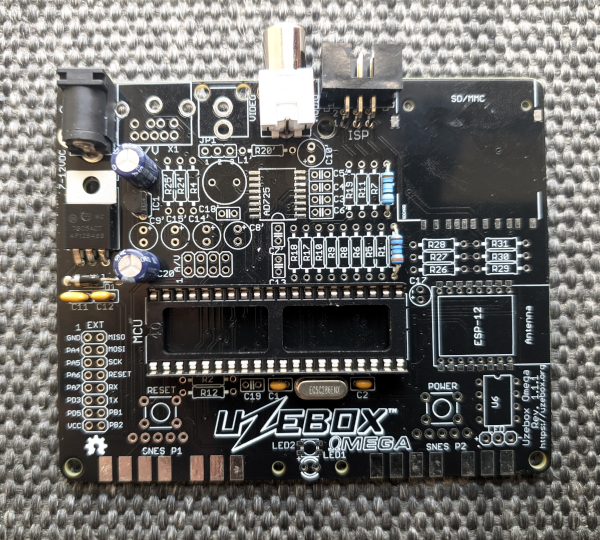
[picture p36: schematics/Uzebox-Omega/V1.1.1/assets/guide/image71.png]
        <td width="50%"></td>
        <td>Add the DIP-40 socket and ensure the DIP socket notch is aligned with the MCU's notch as drawn on the PCB. Whilst holding the DIP socket in place on the PCB, you can use a ruler or a file to bend the sockets legs inwards to hold it steady whilst soldering. Add <b>XTAL</b> (crystal), <b>C1</b> and <b>C2</b> (18pF), <b>R3</b> (806Ω), <b>R22</b> (3.16KΩ), <b>AUDIO</b> jack (white or red) and the <b>ISP header.</b></td>
    </tr>
    <tr>
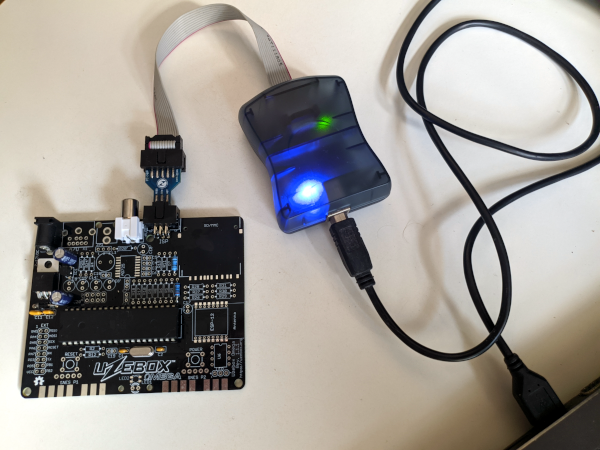
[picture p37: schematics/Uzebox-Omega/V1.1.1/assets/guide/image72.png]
        <td></td>
        <td>Insert the <b>MCU</b> (ATmega644) into the DIP-40 socket. Notice one end of the chip has a notch. You must insert the MCU so that this notch is aligned with the notch in the MCU silkscreen outline drawn on the top of the PCB.<br/><br/>To test that the audio jack and microcontroller are working, we need to use <b>avrdude</b> to flash the fuse settings of the microcontroller and also write a <b>.hex</b> of a Uzebox game to it. This requires that you connect your Uzebox's ISP header to a USB port on your computer using any avrdude compatible programmer.<br/><br/>The commands to flash the fuse settings and Uzebox ROM are covered on the Uzebox wiki's <a href="https://uzebox.org/wiki/Avrdude">Avrdude page.</a> Note that your Uzebox does not need to be powered when using avrdude, it is recommended that it is disconnected from the mains during the flashing process.<br/><br/>You can use any Uzebox rom that you can find a .hex file for to do this audio test, the only requirement is that the rom must automatically start playing music or sound because you'll be testing without a controller at first. The Arkanoid demo in the Uzebox github repository starts playing music as soon as it runs. I prefer to use <a href="https://uzebox.org/forums/viewtopic.php?p=33065#p33065">IKD.hex</a> because it's a good example of the Uzebox sound engine.</td>
    </tr>
    <tr>
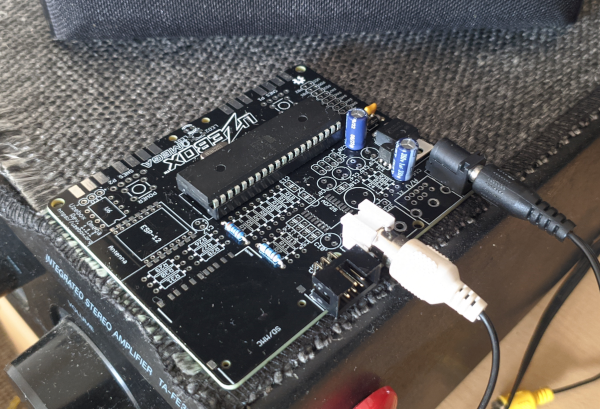
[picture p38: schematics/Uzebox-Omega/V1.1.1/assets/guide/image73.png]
        <td></td>
        <td>Connect the RCA audio jack of the Uzebox to an RCA input on an amplifier or a TV with a RCA audio input jack. Make sure the volume of the TV or amp is about half way up and then attach power to the Omega. The Uzebox powers on automatically and boots straight into whichever ROM you chose to flash so you should be able to hear your chosen rom running if all is well.<br/><br/>Congratulations if you can hear it, give yourself a pat on the back!</td>
    </tr>
</table>

### Assembling the video section

<table>
    <tr>
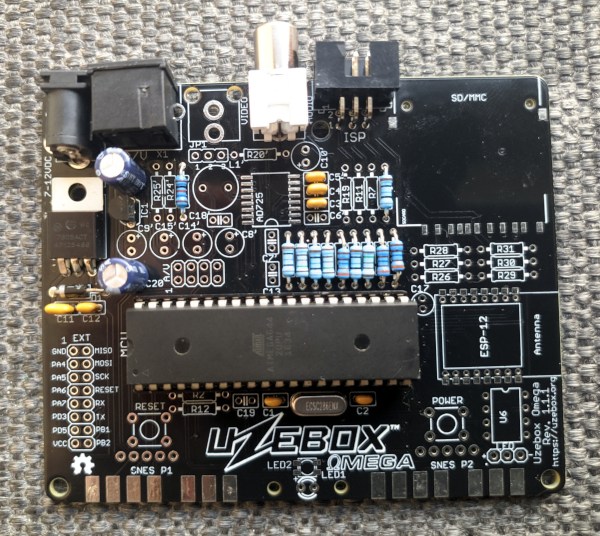
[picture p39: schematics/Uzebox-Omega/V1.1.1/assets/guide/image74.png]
      <td width="50%"></td>
      <td>Assemble the video DAC by soldering <b>R1</b> (3.16KΩ), <b>R4</b> (162Ω), <b>R5</b> (1.58KΩ), <b>R6</b> (806Ω), <b>R8</b> (3.16KΩ), <b>R9</b> (1.58KΩ), <b>R10</b> (806Ω), <b>R17</b> (1.58KΩ), <b>R18</b> (806Ω) and <b>C3</b> (100nF), <b>C4</b> (100nF), <b>C5</b> (100nF). Cut all remaining pins and solder the 9 pin mini DIN socket.<br/><br/>NOTE: <b>R4</b> wasn't required by Uzebox v1.3.3. If you don't have a 162Ω resistor you can use one in the range 150Ω to 220Ω.</td>
    </tr>
    <tr>
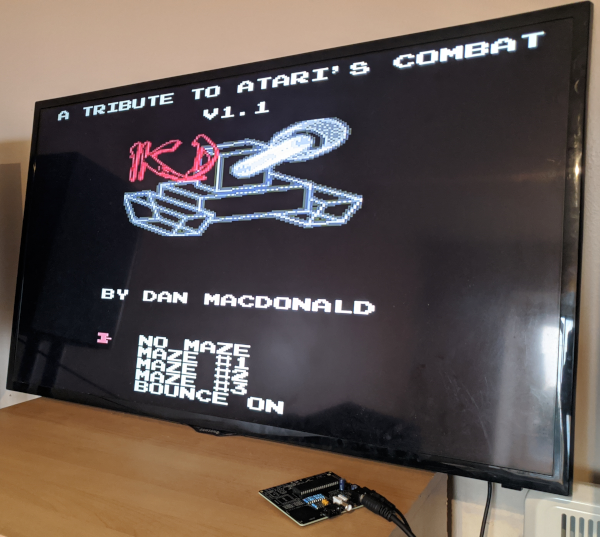
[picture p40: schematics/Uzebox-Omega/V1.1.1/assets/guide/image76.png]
        <td></td>
        <td>Connect the SCART cable to your TV (or a <a href="https://uzebox.org/wiki/Uzebox_SCART_Interface#SCART_to_HDMI_converters">RGB SCART to HDMI converter</a>), then plug in the power. If you are using a CSYNC cable and your TV is configured to the right input, you should be able to see the video and hear the audio output from your Uzebox on your display. Give yourself a double pat on the back!</td>
    </tr>
    <tr>
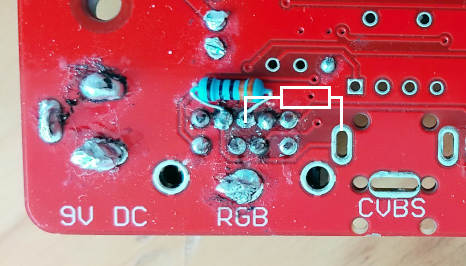
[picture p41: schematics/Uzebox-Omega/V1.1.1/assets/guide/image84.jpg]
        <td></td>
        <td>If you are using a CVBS cable you have to apply the <a href="https://uzebox.org/wiki/Omega#Known_issues_and_fixes">video sync fix.</a> It is recommended that users of Omega versions v1.1 to v1.4 apply this fix. Use a resistor rated at least 100mW and between 300R and 600R. The Uzebox Omega BOM uses a 562R 250mW resistor for this fix.<br/><br/>This image shows an alternate wiring for the resistor on v1.4 models outlined in white. Note that you will get dulled, less vibrant colours using this fix on the Omega v1.4 so you should stick to using CSYNC cables for Omega v1.4.</td>
    </tr>
</table>

### Assembling the SD card section

<table>
    <tr>
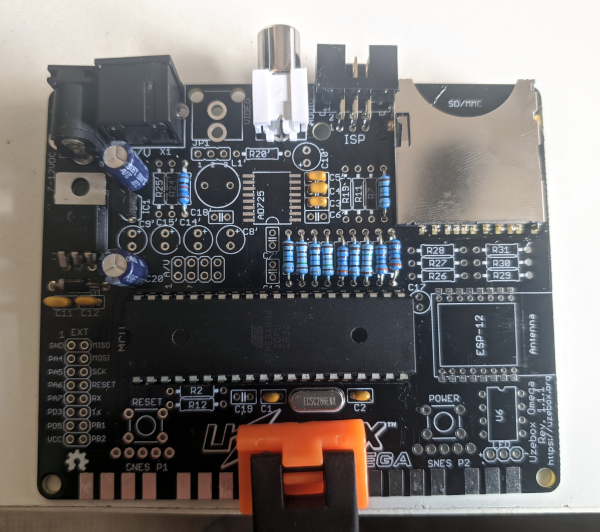
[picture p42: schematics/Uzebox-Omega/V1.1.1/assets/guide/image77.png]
        <td width="50%"></td>
        <td>The SD card socket is the trickiest component to solder, as the only SMD component of the Omega. Make sure the PCB is well lit and do not try to to solder the SD card socket if its late, you're angry or intoxicated.<br/><br/>If your SD socket includes one, keep the plastic retainer in place when soldering. It is recommended that you apply a thin layer of solder flux to the SD socket pads before soldering and that you use both a narrow gauge of solder wire, such as 0.3 to 0.5 mm and use a narrow, finely pointed soldering iron tip.<br/><br/>If you have a PCB assembly station or some helping hands availble to keep the board steady then you'll want to use them when soldering the SD socket, otherwise you may wish to clamp the PCB to your desk to keep it steady.<br/><br/>You may find it helpful to solder the two SD socket pads that are nearest to the edge of the PCB first to keep it anchored before you solder the rest of the SD socket legs.<br/><br/>Feel free to remove the MCU from its DIP socket to give you a bit more room whilst soldering and try to avoid soldering the SD socket legs to the case of the SD card socket.</td>
    </tr>
    <tr>
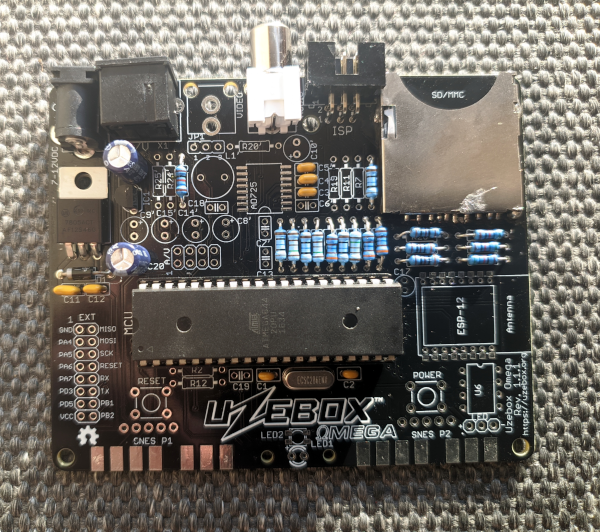
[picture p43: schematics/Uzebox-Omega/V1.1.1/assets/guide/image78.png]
        <td></td>
        <td>Complete the SD interface by soldering the voltage dividers <b>R26</b>(301Ω), <b>R27</b>(301Ω), <b>R28</b>(301Ω), <b>R29</b>(562Ω), <b>R30</b>(562Ω) and <b>R31</b>(562Ω) and then use <b>avrdude</b> to flash the <a href="https://uzebox.org/forums/viewtopic.php?t=9405">bootloader (Bootloader5.hex)</a> to the Uzebox so that you can test the SD card socket works by powering on your Uzebox and then inserting a <a href="https://uzebox.org/wiki/FAQ#What_is_the_recommended_way_to_format_a_SD_card_for_use_with_the_Uzebox?">FAT16 formatted SD card</a> with some <b>.uze</b> files on it to see if the bootloader lists the programs on the card. If it does, you're well on your way to having a fully working Uzebox.</td>
    </tr>
</table>

### Assembling the remaining parts

<table>
    <tr>
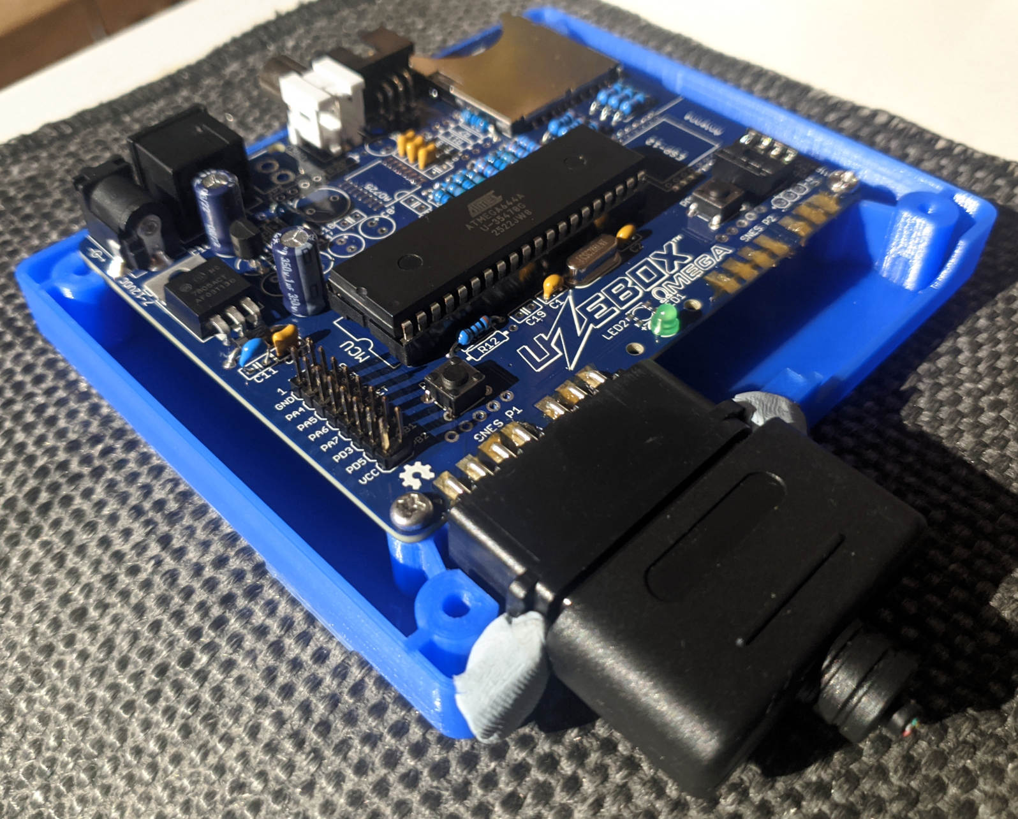
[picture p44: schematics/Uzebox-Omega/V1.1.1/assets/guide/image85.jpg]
        <td></td>
        <td>Solder the SNES connectors. It is highly recommended that you apply some solder flux to the SNES connector pads before positioning the connectors, this will help the solder stick to the pads.<br/><br/>If you have the <a href="https://uzebox.org/wiki/3D_printed_case">3D printed Uzebox case</a> then the best way to solder the SNES connectors is to screw the Uzebox into the lower part of the case, align the connectors and then solder them whilst the PCB is in the case. Otherwise, you can use the following method.<br/><br/>If you don't have the Uzebox case, the Uzebox PCB needs to be raised by a few millimeters so that the pins of the SNES connectors lie flat on the pads with no gap. You can use a couple of credit/swipe cards stacked upon one another or several sheets of paper inserted below the PCB (but not under the connectors) to elevate the PCB to the right height so that the connector pins lie flat on the pads.<br/><br/>Hold the connectors firmly and center the pins in the middle of the pads, ensuring that there is no gap between the connector casing and the PCB. Once the connector is correctly positioned, use a small amount of Blu Tack or similar putty to keep the connectors in place whilst soldering. Having a SNES controller connected whilst soldering will prevent any of the pins getting misaligned by the heat of the soldering iron.<br/><br/>Begin soldering by heating just the pad for a second or two then both the pin and the pad then add solder, a lot of solder! Gently stroke the solder from the pin to the pad to bond the two. It’s easier to solder pins at both extremities of the connector first. The SNES connector plastic won't withstand a ton of heat before becoming loose, so solder them quickly. Use enough solder to ensure it will have good mechanical resistance.<br/><br/>After soldering the SNES connectors you can run the <a href="https://uzebox.org/wiki/Controller_Tester">Controller Tester</a> program, <b>ControllerTester.uze</b> from the demos folder of the Uzebox github repository to test that your joypads, joysticks and buttons all function correctly.</td>
    </tr>
    <tr>
        <td width="50%"></td>
        <td>Add the <b>RESET</b> and <b>POWER</b> switches, <b>R2</b>(301Ω) and <b>LED1</b>. The longest pin on the LED is the anode and must be inserted in the hole with a little <b>+</b> next to it. Ensure the tactile switches are mounted horizontally as pictured.<br/><br/>You can also optionally solder the EXT header if you want to experiment with <a href="https://uzebox.org/wiki/UART">UART and UART MIDI</a> or you wish to use the Uzenet module via the EXT header.<br/><br/>If you're not using a <a href="https://uzebox.org/wiki/ESP8266">Uzenet module</a> you can add 128 KB of SPI SRAM by adding an 8 position DIP socket and an SPI SRAM chip. Remember to get the notch aligned when inserting the SPI DIP socket or the chip itself.</td>
    </tr>
    <tr>
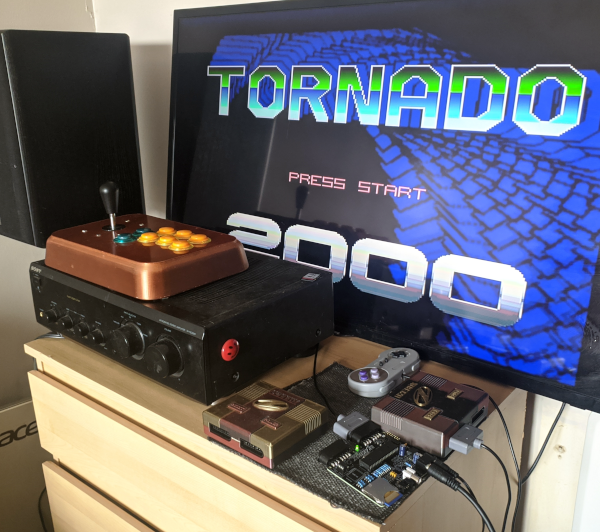
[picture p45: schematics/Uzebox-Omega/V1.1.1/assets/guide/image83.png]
        <td></td>
        <td>Plug a Uzebox compatible <a href="https://uzebox.org/wiki/Joystick">joystick</a> or <a href="https://uzebox.org/wiki/FAQ#Where_can_I_buy_Uzebox_compatible_controllers?">joypad</a> into the P1 controller port, connect the mini DIN socket to your RGB SCART TV. Insert a FAT16 formatted SD card containing some <b>.uze</b> files and then insert the power cable to test everything.<br/><br/><a href="https://uzebox.org/wiki/Tornado_2000">Tornado 2000</a> is useful to test the SD card socket because it won't run without a data file stored on the SD card.<a href="https://uzebox.org/forums/viewtopic.php?t=11717">Uzemod</a>, a MOD music file player, and <a href="https://uzebox.org/forums/viewtopic.php?t=11725">UzeboxPC</a>, an 8086 PC emulator that lets you run CP/M are useful for testing SPI SRAM because they won't run without it. You also need a <a href="https://uzebox.org/wiki/Uzebox_Keyboard_Interface">Uzebox PS/2 keyboard adapter</a> to run UzeboxPC.<br/><br/>Do not try to use the bare Uzebox on a metal or any other conductive surface without it being encased in at least the bottom half of a case to prevent shorts and damage to the hardware. It is recommended that you build the Uzebox 3D printed case or design your own to help protect it.<br/></br><b>IMPORTANT</b> The Uzebox bootloader (aka the <b>Gameloader</b>) allows you to load games stored on SD card. To enter the bootloader, hold any button on the P1 controller while pressing and releasing the reset button. Whilst in a game, you can push <b>Select+Start+Y+B</b> to reset the game and get back to the gameloader.<br/><br/>Have fun!</td>
    </tr>
</table>

## Troubleshooting
Head to the [Uzebox forum](https://uzebox.org/forums) for support assembling the Uzebox Omega. The [Uzebox wiki](https://uzebox.org/wiki) also contains a wealth of information.

## Assembly guides for older Uzebox versions
To assemble older version of the Uzebox (before version 5.0 / F5), you can refer to the [archived assembly guide](http://uzebox.org/files/UzeboxAssemblyGuideV1.7.pdf).

## Recommended AVR ISP Programmers 
An ISP programmer is required to flash the ATMega644 with the bootloader and games. Common models are:
* Atmel/Microchip AVRISP MK2 clones (Digikey, Amazon, AliExpress)
* Olimex AVR-ISP-MK2 (Mouser)
* Arduino (Everywhere. Search for "USBASP AVR programmer")

## Recommended shielded CSYNC RGB SCART cables

[Sega Mega Drive 2 / Genesis 2 RGB SCART PACKAPUNCH PRO CABLE](https://www.retrogamingcables.co.uk/sega-mega-drive-2-sega-genesis-2-rgb-av-scart-cable-tv-lead)

[Sega Mega Drive/Genesis 2 RGB SCART Cable](https://www.retroupgrades.co.uk/product/md2-scart/)

## Uzebox Omega compatible SCART to HDMI converters

The advantages of the [LEVELHIKE HDMI converter cable](https://www.amazon.com/gp/product/B07Z5W7QS7/) are its small size and its integrated cable means you don't also need to buy a shielded cable to get good sound quality from the SCART cable. The down side is that it is only really compatible with the Mega Drive and the Uzebox Omega.

[LiNKFOR SCART to HDMI Converter](https://www.amazon.co.uk/LiNKFOR-Converter-Adapter-Supports-Headphone-Scart-HDMI/dp/B078JJMR5J/)

[deleyCON SCART to HDMI Converter](https://www.amazon.es/dp/B06XR89RZN?ref=ppx_yo2ov_dt_b_fed_asin_title)

The Open Source Scan Converter has trouble maintaining video sync for some Uzebox programs that use sound and thus is not recommended.
<br/><br/>
Creative Commons BY-SA

Pictures and content of this document are released under a [Creative Commons Attribution-Share Alike 3.0 Unported License](http://creativecommons.org/licenses/by-sa/3.0/).  
Uzebox is a reserved trademark.  
Copyright © Belogic

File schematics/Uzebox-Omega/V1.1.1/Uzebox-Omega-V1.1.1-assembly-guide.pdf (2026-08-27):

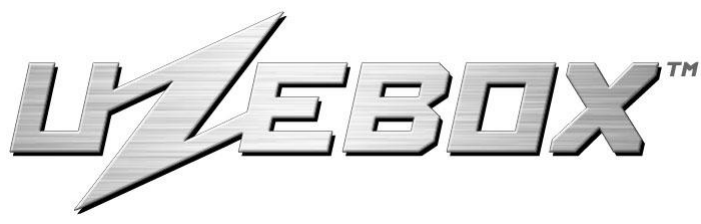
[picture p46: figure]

# Uzebox Omega assembly guide

For Uzebox Omega Revision V1.1 to v1.4

[!NOTE]
This assembly guide was written with consideration of the electronics beginner who only has a minimal set of tools. Some of the methods described in this guide are makeshift solutions for those without more professional tooling. Use the method which works best for you.

## Revision History

Version | Date | Author | Description
0 | 01-Nov-2012 | A.Bourque | Initial release
1 | 6-Nov-2012 | A.Bourque | Minor corrections
2 | 28-Jan-2014 | A.Bourque | Minor changes
3 | 27-Jan-2015 | A.Bourque | Added replacement parts for EXT header and SD card socket
4 | 21-Feb-2015 | A.Bourque | Added preliminary troubleshooting section
5 | 26-Nov-2015 | A.Bourque | Minor improvements
6 | 1-Feb-2016 | A.Bourque | Added note regarding power button

Version | Date | Author | Description
7 | 15-Nov-2016 | A.Bourque

Added notes for
PCB rev 1.3.1 and
references to the
Uzenet interface.
8 | 13-Aug-2024 | A.Bourque | Ported the assembly guide to GitHub and added minor improvements.
9 | 28-Aug-2024 | D.MacDonald | Several additions and improvements.
10 | 17-Sep-2024 | D.MacDonald

Add solder flux, a
video cable and a
SNES controller to
the “Other parts
required” table.
11 | 11-Jul-2025 | D.MacDonald

Started work on
modifying the
Uzebox assembly
guide for the
Uzebox Omega.

## Parts list verification

[!IMPORTANT]
Ensure you have all the required parts before starting,
Component Image | | Schematic
Reference | Description


N/A

Uzebox Omega
printed circuit
board (PCB)
N/A | DC power jack

Component Image | Schematic
Reference | Description

AUDIO

Audio output RCA
jack (Red or white) -
optional
X1 | A female, 9 pin mini DIN socket

ISP

Right-angled
Atmega644
programming ports
are preferred over
vertical ones.
EXT | Extension port header - optional
MCU | DIP-40 socket for the Atmega644
POWER / RESET | Tactile switches (x2)

SD/MMC

Secure Digital
memory card
socket. One of the
two possible models
has a soldering
wing on the right
side only.

Component Image | Schematic
Reference | Description

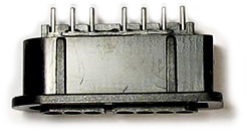
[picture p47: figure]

SNESP1 SNESP2 | SNES gamepad connectors (x2)


C1,C2 | 18pF ceramic capacitors
C3,C4,C5, C12 | .10uF (100nF) ceramic capacitors
C11 | .33uF (330nF) ceramic capacitor

R2,R26, R27,R28

Resistor 301Ω 1%
(Orange, black,
brown, black,
brown)

R29,R30, R31, video
fix

Resistor 562Ω 1%
(Green, blue, red,
black, brown)

R3,R6,R10,R18

Resistor 806Ω 1%
(Gray, black, blue,
black, brown)

R5,R9,R17

Resistor 1.58KΩ 1%
(Brown, green, gray,
brown, brown)

R1,R8,R22

Resistor 3.16KΩ 1%
(Orange, brown,
blue, brown,
brown)

Component Image | Schematic
Reference | Description
MCU | ATmega644 microcontroller
XTAL | 28.63636Mhz crystal
IC1 | 3.3V voltage regulator
IC2 | 5.0V voltage regulator
D1 | Rectifier diode
LED1 | Power LED
U6 | SPI SRAM socket - optional
U6 | 1Mb (128KB) SPI SRAM IC - optional

## Tools required

To assemble this kit you will need the following tools:

Tool | Description


A basic soldering iron, 25W-40W.


Solder, rosin core, 60/40 type.

Long nose pliers.


Regular cutters will do fine, but shear cutters will do a better job.


A basic multimeter is not essential but highly recommended for verifications and troubleshooting.

An AVR ISP programmer. Required to flash the Atmega644 microcontroller. Alternately, you can flash the Atmega using avrdude (https://uzebox.org/wiki/Avrdude) and the GPIO header of a Raspberry Pi or similar.

## Other parts required

Part | Description


A standard 7-12VDC barrel connector power supply with a center-positive, 5.5x2.1mm tip. See the Omega’s text BOM for a few suitable DigiKey PSUs.


A Sega Mega Drive 2 / Sega Genesis 2 compatible 9 pin mini DIN to RGB SCART cable. Shielded, CSYNC cables (https://uzebox.org/wiki/Uzebox_SCART_Interface#SCART_cables) are recommended for the best sound and video quality.

A SNES controller. (https://uzebox.org/wiki/FAQ#Where_can_I_buy_Uzebox_compatible_controllers?)


Solder flux. Not strictly required but flux makes it much easier to solder the SNES connectors and SD card socket.

## Building the kit

Assembling the power supply section

If your power jack is too far out of alignment it can prevent you correctly inserting the mini DIN AV socket. I use Blu Tack or some other putty-like adhesive to keep the power jack correctly aligned whilst soldering it.

Insert the DC barrel jack. It is recommended that you start by soldering the power jack first. The main reason being it is quite easy to solder the power jack at an angle with the PCBs that use the circular power jack footprints instead of using slots, as used on later revisions of the Omega. The power jack can be tricky to desolder if you don’t own a desoldering station/ gun so if you mess up by not soldering the power jack on straight enough then you may as well start over with a new PCB if you don’t own any desoldering tools.

Bend the pins on the soldering side to keep it held firmly in place. To ensure it’s soldered flat, you can also put the 40 pin DIP socket underneath the PCB to level it up. Be sure to put plenty of solder on the three pins so that the jack is securely mounted.
Using pliers, bend the pins of IC2, the 5V voltage regulator, at a 90 degrees angle as pictured. Alternately, insert the legs into the PCB up to the notches then bend the top part until it is lying flat on the PCB. Whilst holding the regulator flat, use the edge of a ruler or maybe a file to bend the regulators legs flat against the PCB on the underside of the board. Mount IC2 on the PCB along diode D1. Notice the diode has a white stripe on one end to indicate the direction of current. Ensure the band matches with the component’s drawing on the PCB. As with all future components you will solder, when inserting a component, bend its pins on the other side of the PCB so it holds in place. Flip the PCB and solder all pins.


Using the cutters, cut the pins excess wire. It is recommended that you wear eye protection when using wire cutters. You should hold wires whilst cutting them to stop the wire bits flying into someones eye.


Add C11 (.33uF), C12 (100nF), C16 (1uF), C20 (1uF) and IC1 (3.3v regulator). The electrolytic capacitors (the black or dark blue cans) have a polarity. The negative pin is marked with a white stripe and little minus signs on the side. Ensure the opposite pin (the longest one) inserts in the hole which has a little “+” next to it. Solder all pins and remove excess wire. That completes the power supply section.
If you have a multimeter, let’s test what we have so far. Switch your multimeter to DC voltage measurement mode. Plug in the power supply and probe pin 1 and 7 on the P1 SNES connector footprint. If all goes well, you should measure around 5V. Unplug the power.

If you aren’t getting around 5V, check your soldering. It’s more likely to be a soldering issue than faulty components if you are new to soldering and the components are new. Heat up your soldering iron and touch up all of the solder joints made so far on the underside of the PCB then try another voltage measurement.

If you have a hot air gun you can try reflowing the joints. Heating the solder until you can see it start to melt without then using a solder sucker or wick to remove any of it can often fix substandard or faulty solder joints.


Assembling the microcontroller and sound section


Add the DIP-40 socket and ensure the DIP socket notch is aligned with the MCU’s notch as drawn on the PCB. Whilst holding the DIP socket in place on the PCB, you can use a ruler or a file to bend the sockets legs inwards to hold it steady whilst soldering. Add XTAL (crystal), C1 and C2 (18pF), R3 (806Ω), R22 (3.16KΩ), AUDIO jack (white or red) and the ISP header.

Insert the MCU (ATmega644) into the DIP-40 socket. Notice one end of the chip has a notch. You must insert the MCU so that this notch is aligned with the notch in the MCU silkscreen outline drawn on the top of the PCB.

To test that the audio jack and microcontroller are working, we need to use avrdude to flash the fuse settings of the microcontroller and also write a .hex of a Uzebox game to it. This requires that you connect your Uzebox’s ISP header to a USB port on your computer using any avrdude compatible programmer.


The commands to flash the fuse settings and Uzebox ROM are covered on the Uzebox wiki’s Avrdude page. (https://uzebox.org/wiki/Avrdude) Note that your Uzebox does not need to be powered when using avrdude, it is recommended that it is disconnected from the mains during the flashing process.

You can use any Uzebox rom that you can find a .hex file for to do this audio test, the only requirement is that the rom must automatically start playing music or sound because you’ll be testing without a controller at first. The Arkanoid demo in the Uzebox github repository starts playing music as soon as it runs. I prefer to use IKD.hex (https://uzebox.org/forums/viewtopic.php?p=33065#p33065) because it’s a good example of the Uzebox sound engine.
Connect the RCA audio jack of the Uzebox to an RCA input on an amplifier or a TV with a RCA audio input


jack. Make sure the volume of the TV or amp is about half way up and then attach power to the Omega. The Uzebox powers on automatically and boots straight into whichever ROM you chose to flash so you should be able to hear your chosen rom running if all is well.

Congratulations if you can hear it, give yourself a pat on the back!

Assembling the video section

Assemble the video DAC by soldering R1 (3.16KΩ), R4 (162Ω), R5 (1.58KΩ), R6 (806Ω), R8 (3.16KΩ), R9 (1.58KΩ), R10 (806Ω), R17 (1.58KΩ), R18 (806Ω) and C3 (100nF), C4 (100nF), C5 (100nF). Cut all remaining pins and solder the 9 pin mini DIN socket.

NOTE: R4 wasn’t required by Uzebox v1.3.3. If you don’t have a 162Ω resistor you can use one in the range 150Ω to 220Ω.
Connect the SCART cable to your TV (or a RGB SCART to HDMI converter), (https://uzebox.org/wiki/Uzebox_SCART_Interface#SCART_to_HDMI_converters) then plug in the power. If you are using a CSYNC cable and your TV is configured to the right input, you should be able to see the video and hear the audio output from your Uzebox on your display. Give yourself a double pat on the back!
If you are using a CVBS cable you have to apply the video sync fix. (https://uzebox.org/wiki/Omega#Known_issues_and_fixes) It is recommended that users of Omega versions v1.1 to v1.4 apply this fix. Use a resistor rated at least 100mW and between 300R and 600R. The Uzebox Omega BOM uses a 562R 250mW resistor for this fix.


This image shows an alternate wiring for the resistor on v1.4 models outlined in white. Note that you will get dulled, less vibrant colours using this fix on the Omega v1.4 so you should stick to using CSYNC cables for Omega v1.4.


Assembling the SD card section

The SD card socket is the trickiest component to solder, as the only SMD component of the Omega. Make sure the PCB is well lit and do not try to to solder the SD card socket if its late, you’re angry or intoxicated.

If your SD socket includes one, keep the plastic retainer in place when soldering. It is recommended that you apply a thin layer of solder flux to the SD socket pads before soldering and that you use both a narrow gauge of solder wire, such as 0.3 to 0.5 mm and use a narrow, finely pointed soldering iron tip.

If you have a PCB assembly station or some helping hands availble to keep the board steady then you’ll want to use them when soldering the SD socket, otherwise you may wish to clamp the PCB to your desk to keep it steady.


You may find it helpful to solder the two SD socket pads that are nearest to the edge of the PCB first to keep it anchored before you solder the rest of the SD socket legs.

Feel free to remove the MCU from its DIP socket to give you a bit more room whilst soldering and try to avoid soldering the SD socket legs to the case of the SD card socket.
Complete the SD interface by soldering the voltage dividers R26(301Ω), R27(301Ω), R28(301Ω), R29(562Ω), R30(562Ω) and R31(562Ω) and then use avrdude to flash the bootloader (Bootloader5.hex) (https://uzebox.org/forums/viewtopic.php?t=9405) to the Uzebox so that you can test the SD card socket works by powering on your Uzebox and then inserting a FAT16 formatted SD card (https://uzebox.org/wiki/FAQ#What_is_the_recommended_way_to_format_a_SD_card_for_use_with_the_Uzebox?) with some .uze files on it to see if the bootloader lists the programs on the card. If it does, you’re well on your way to having a fully working Uzebox.


Assembling the remaining parts

Solder the SNES connectors. It is highly recommended that you apply some solder flux to the SNES connector pads before positioning the connectors, this will help the solder stick to the pads.

If you have the 3D printed Uzebox case (https://uzebox.org/wiki/3D_printed_case) then the best way to solder the SNES connectors is to screw the Uzebox into the lower part of the case, align the connectors and then solder them whilst the PCB is in the case. Otherwise, you can use the following method.

If you don’t have the Uzebox case, the Uzebox PCB needs to be raised by a few millimeters so that the pins of the SNES connectors lie flat on the pads with no gap. You can use a couple of credit/swipe cards stacked upon one another or several sheets of paper inserted below the PCB (but not under the connectors) to elevate the PCB to the right height so that the connector pins lie flat on the pads.

Hold the connectors firmly and center the pins in the middle of the pads, ensuring that there is no gap between the connector casing and the PCB. Once the connector is correctly positioned, use a small amount of Blu Tack or similar putty to keep the connectors in place whilst soldering. Having a SNES controller connected whilst soldering will prevent any of the pins getting misaligned by the heat of the soldering iron.

Begin soldering by heating just the pad for a second or two then both the pin and the pad then add solder, a lot of solder! Gently stroke the solder from the pin to the pad to bond the two. It’s easier to solder pins at both extremities of the connector first. The SNES connector plastic won’t withstand a ton of heat before becoming loose, so solder them quickly. Use enough solder to ensure it will have good mechanical resistance.

After soldering the SNES connectors you can run the Controller Tester (https://uzebox.org/wiki/Controller_Tester) program, ControllerTester.uze from the demos folder of the Uzebox github repository to test that your joypads, joysticks and buttons all function correctly.

Add the RESET and POWER switches, R2(301Ω) and LED1. The longest pin on the LED is the anode and must be inserted in the hole with a little + next to it. Ensure the tactile switches are mounted horizontally as pictured.


You can also optionally solder the EXT header if you want to experiment with UART and UART MIDI (https://uzebox.org/wiki/UART) or you wish to use the Uzenet module via the EXT header.

If you’re not using a Uzenet module (https://uzebox.org/wiki/ESP8266) you can add 128 KB of SPI SRAM by adding an 8 position DIP socket and an SPI SRAM chip. Remember to get the notch aligned when inserting the SPI DIP socket or the chip itself.
Plug a Uzebox compatible joystick (https://uzebox.org/wiki/Joystick) or joypad (https://uzebox.org/wiki/FAQ#Where_can_I_buy_Uzebox_compatible_controllers?) into the P1 controller port, connect the mini DIN socket to your RGB SCART TV. Insert a FAT16 formatted SD card containing some .uze files and then insert the power cable to test everything.

Tornado 2000 (https://uzebox.org/wiki/Tornado_2000) is useful to test the SD card socket because it won’t run without a data file stored on the SD card.Uzemod, (https://uzebox.org/forums/viewtopic.php?t=11717) a MOD music file player, and UzeboxPC, (https://uzebox.org/forums/viewtopic.php?t=11725) an 8086 PC emulator that lets you run CP/M are useful for testing SPI SRAM because they won’t run without it. You also need a Uzebox PS/2 keyboard adapter (https://uzebox.org/wiki/Uzebox_Keyboard_Interface) to run UzeboxPC.


Do not try to use the bare Uzebox on a metal or any other conductive surface without it being encased in at least the bottom half of a case to prevent shorts and damage to the hardware. It is recommended that you build the Uzebox 3D printed case or design your own to help protect it.

IMPORTANT The Uzebox bootloader (aka the Gameloader) allows you to load games stored on SD card. To enter the bootloader, hold any button on the P1 controller while pressing and releasing the reset button. Whilst in a game, you can push Select+Start+Y+B to reset the game and get back to the gameloader.

Have fun!

## Troubleshooting

Head to the Uzebox forum (https://uzebox.org/forums) for support assembling the Uzebox Omega. The Uzebox wiki (https://uzebox.org/wiki) also contains a wealth of information.

## Assembly guides for older Uzebox versions

To assemble older version of the Uzebox (before version 5.0 / F5), you can refer to the archived assembly guide. (http://uzebox.org/files/UzeboxAssemblyGuideV1.7.pdf)

## Recommended AVR ISP Programmers

An ISP programmer is required to flash the ATMega644 with the bootloader and games. Common models are: * Atmel/Microchip AVRISP MK2 clones (Digikey, Amazon, AliExpress) * Olimex AVR-ISP-MK2 (Mouser) * Arduino (Everywhere. Search for “USBASP AVR programmer”)

## Recommended shielded CSYNC RGB SCART cables

Sega Mega Drive 2 / Genesis 2 RGB SCART PACKAPUNCH PRO CABLE (https://www.retrogamingcables.co.uk/sega-mega-drive-2-sega-genesis-2-rgb-av-scart-cable-tv-lead)

Sega Mega Drive/Genesis 2 RGB SCART Cable (https://www.retroupgrades.co.uk/product/md2-scart/)

## Uzebox Omega compatible SCART to HDMI converters

The advantages of the LEVELHIKE HDMI converter cable (https://www.amazon.com/gp/product/B07Z5W7QS7/) are its small size and its integrated cable means you don’t also need to buy a shielded cable to get good sound quality from the SCART cable. The down side is that it is only really compatible with the Mega Drive and the Uzebox Omega.

LiNKFOR SCART to HDMI Converter (https://www.amazon.co.uk/LiNKFOR-Converter-Adapter-Supports-Headphone-Scart-HDMI/dp/B078JJMR5J/)

deleyCON SCART to HDMI Converter (https://www.amazon.es/dp/B06XR89RZN?ref=ppx_yo2ov_dt_b_fed_asin_title)

The Open Source Scan Converter has trouble maintaining video sync for some Uzebox programs that use sound and thus is not recommended.

Pictures and content of this document are released under a Creative Commons Attribution-Share Alike 3.0 Unported License. (http://creativecommons.org/licenses/by-sa/3.0/)
Uzebox is a reserved trademark.
Copyright © Belogic

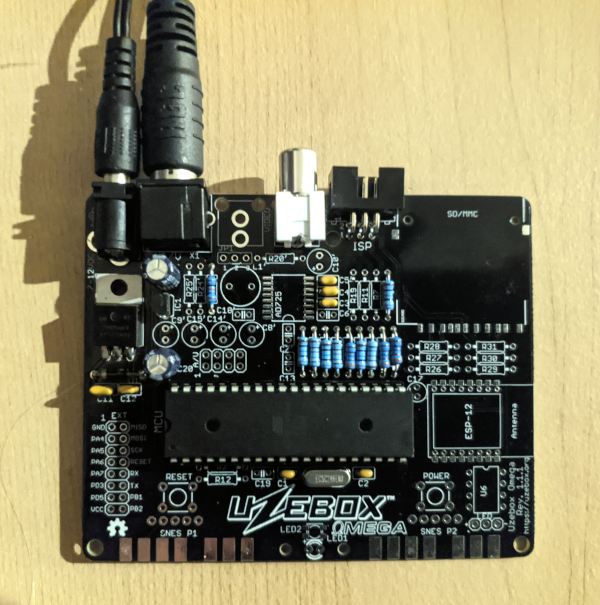
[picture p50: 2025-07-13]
schematics/Uzebox-Omega/V1.1.1/assets/guide/image75.png

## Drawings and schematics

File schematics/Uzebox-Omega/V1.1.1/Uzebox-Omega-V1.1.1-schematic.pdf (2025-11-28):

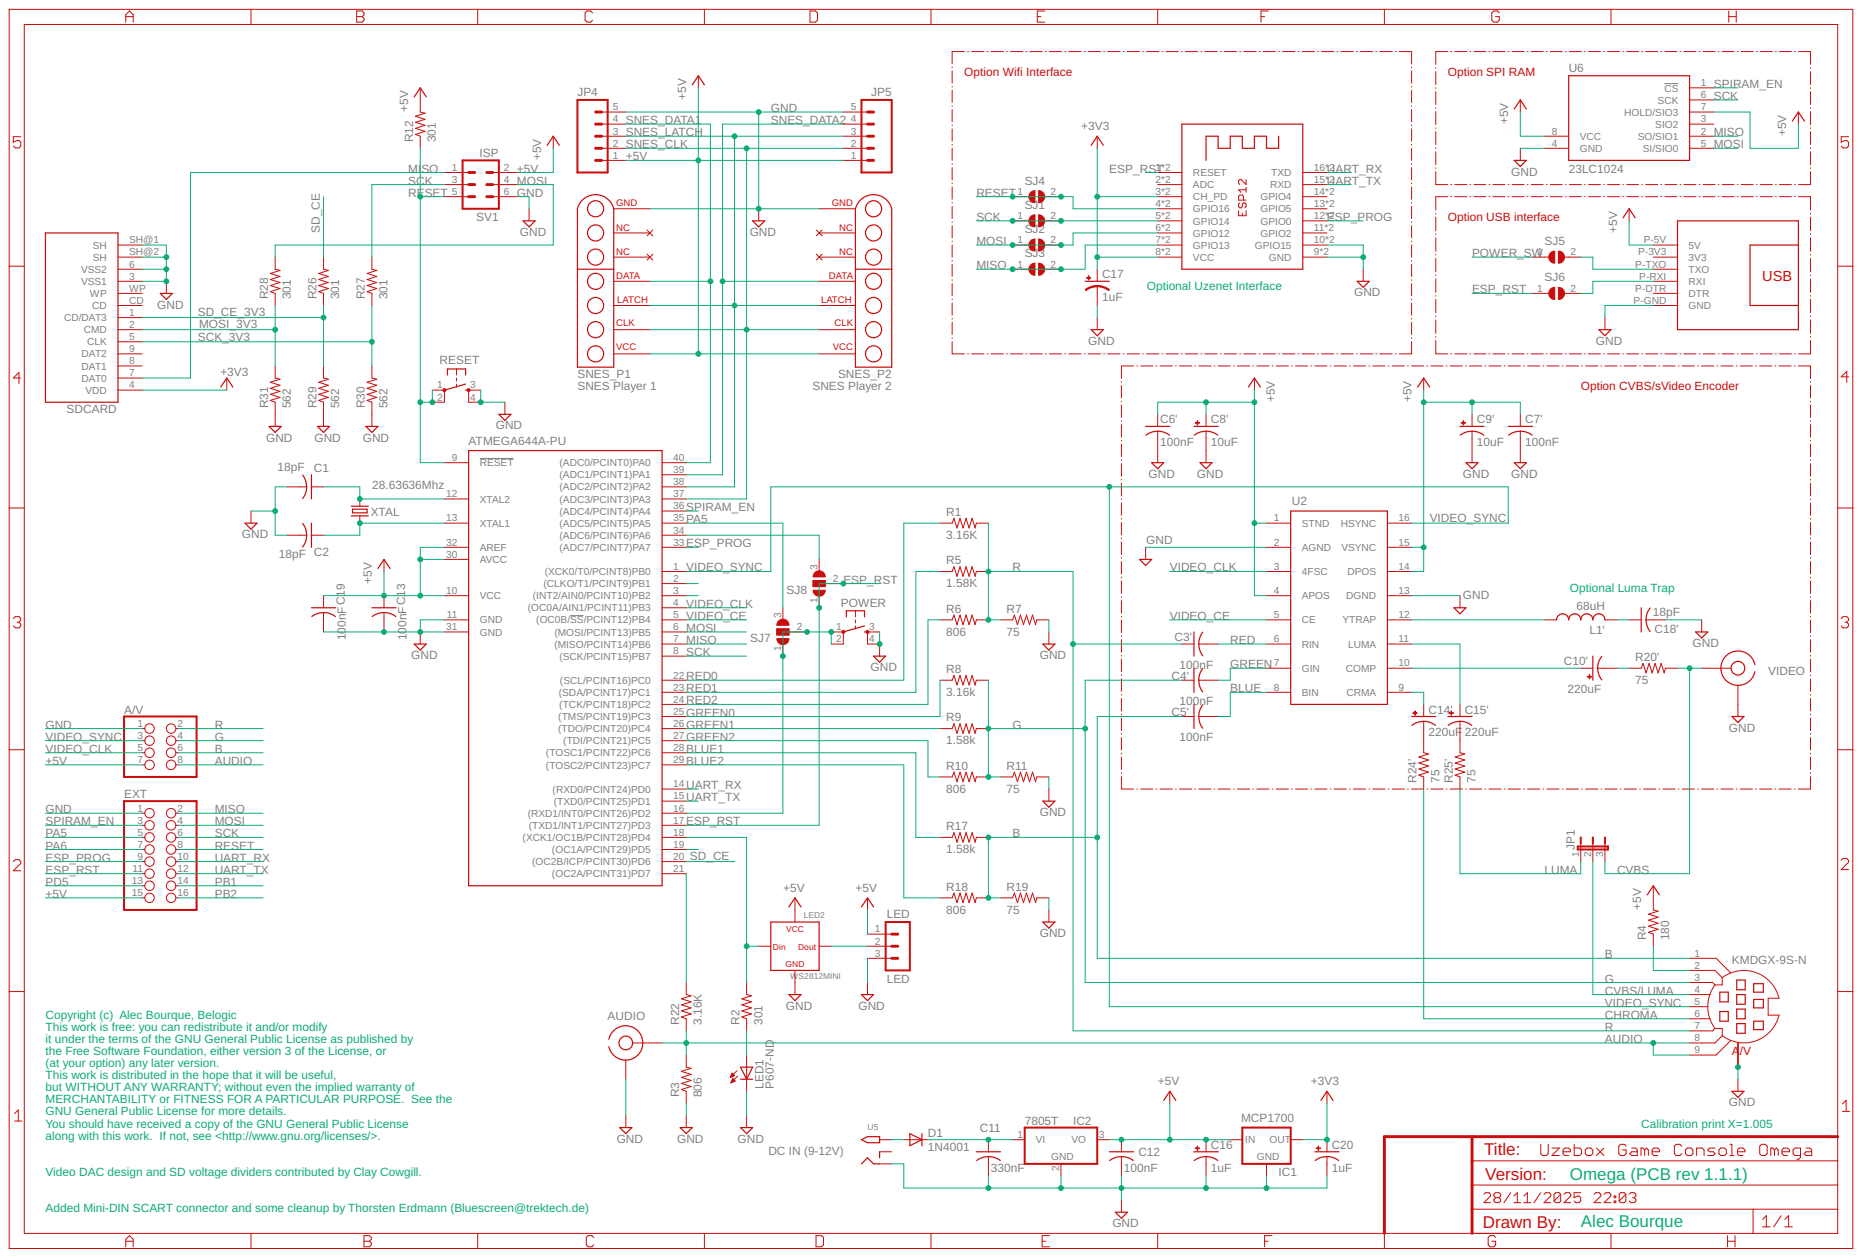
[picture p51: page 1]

Option USB interface GND

MOSI_3V3

CLK | CLK

Option CVBS/sVideo Encoder

24 RED2
25 GREEN0

27 GREEN2
28 BLUE1
29 BLUE2

14 UART_RX UART_TX

Copyright (c) Alec Bourque, Belogic This work is free: you can redistribute it and/or modify

it under the terms of the GNU General Public License as published by
the Free Software Foundation, either version 3 of the License, or
(at your option) any later version. This work is distributed in the hope that it will be useful, but WITHOUT ANY WARRANTY; without even the implied warranty of

MERCHANTABILITY or FITNESS FOR A PARTICULAR PURPOSE. See the GNU General Public License for more details. You should have received a copy of the GNU General Public License

Added Mini-DIN SCART connector and some cleanup by Thorsten Erdmann (Bluescreen@trektech.de)

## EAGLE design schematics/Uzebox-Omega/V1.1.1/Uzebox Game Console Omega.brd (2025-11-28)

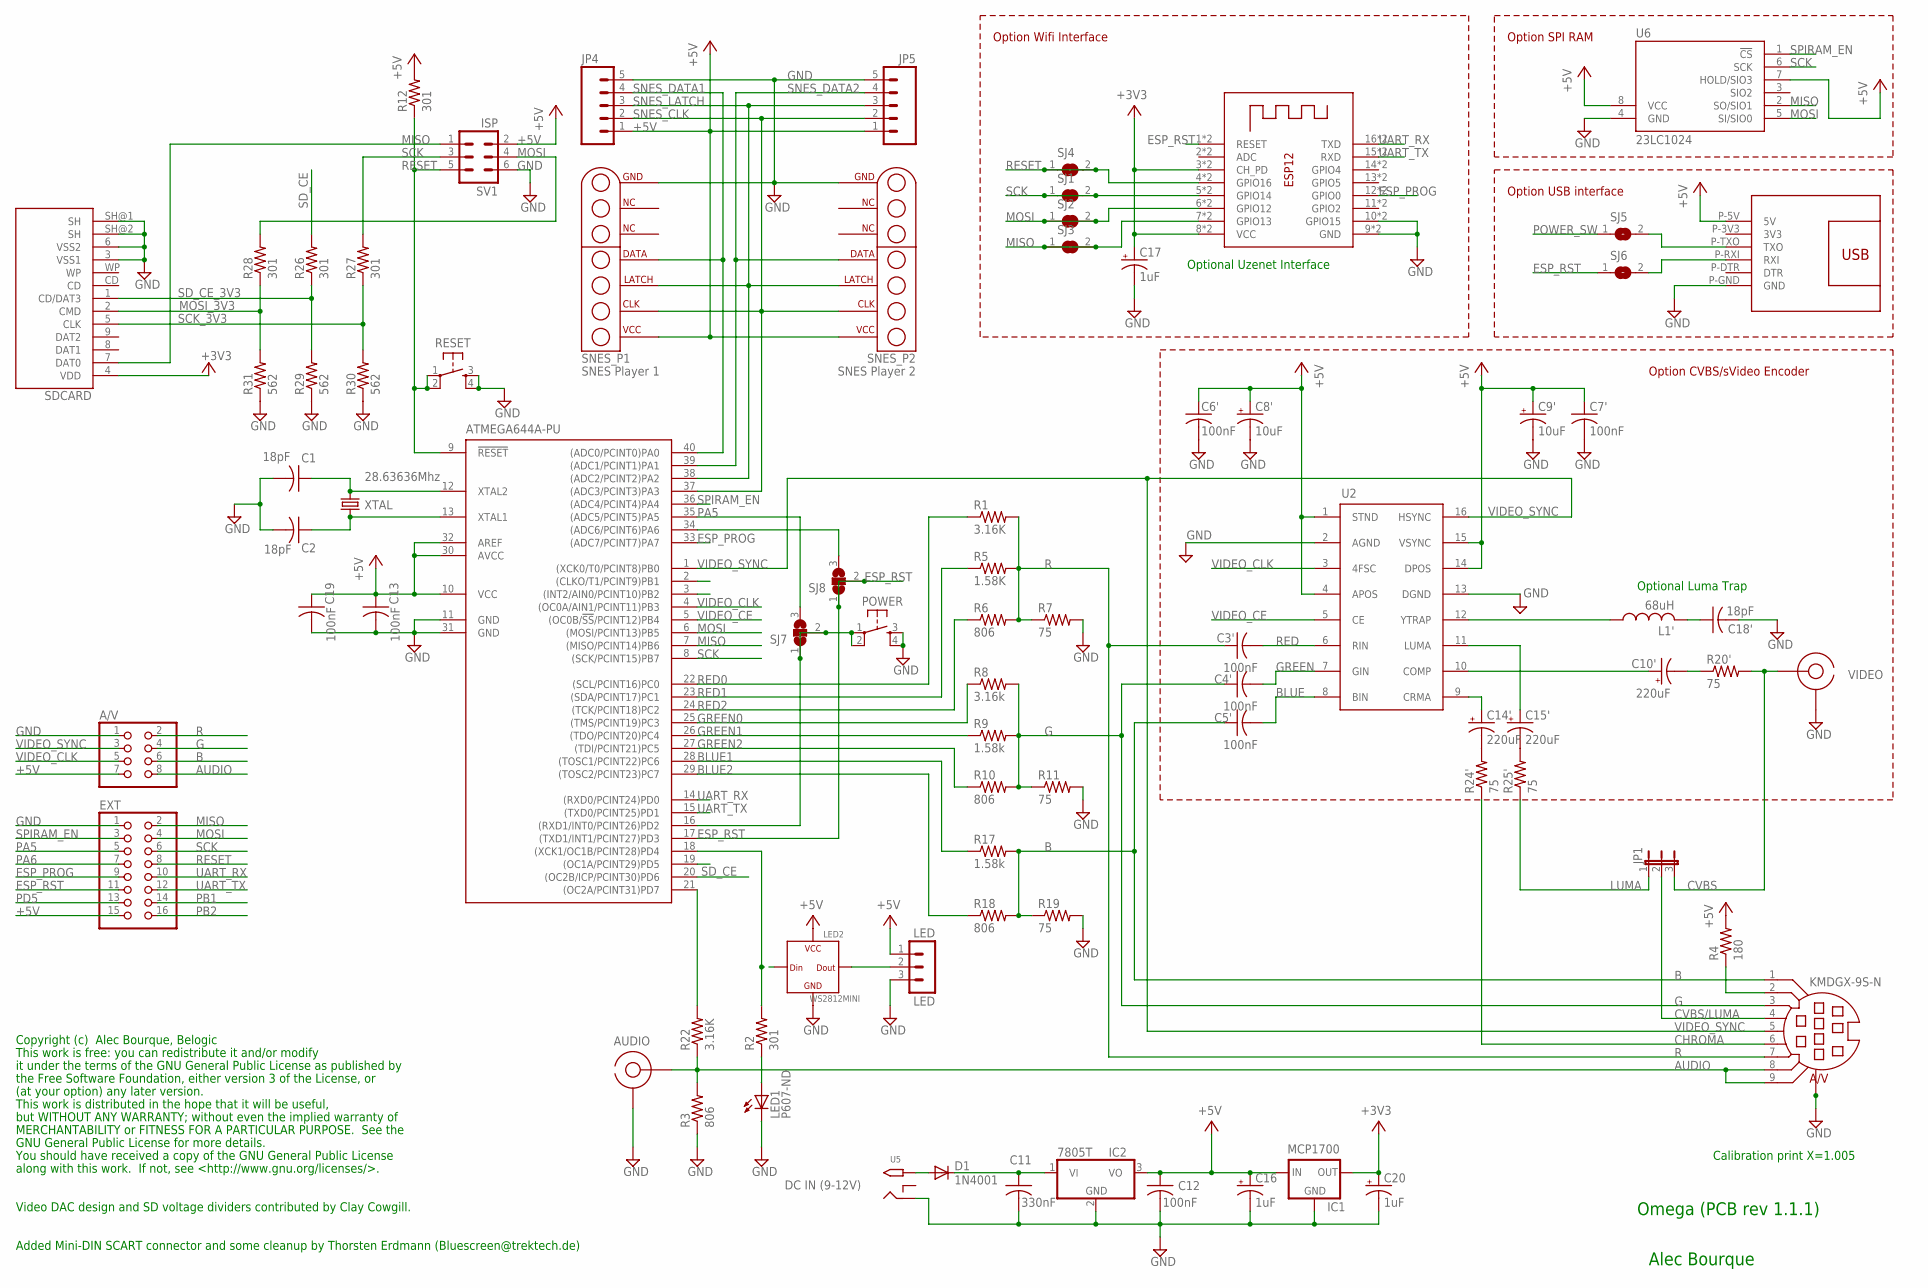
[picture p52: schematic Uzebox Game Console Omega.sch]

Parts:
A/V: PINHD-2X4; 2X04
AD725: AD725; SO16W
ATMEGA644A-PU: MEGA164P/324P/644P-PU; DIL40
AUDIO: RCA
C1, C2, C18': 18pF; C025-025X050
C3', C4', C5', C6', C7', C12, C13, C19: 100nF; C025-025X050
C8', C9': 10uF; E2,5-6
C10', C14', C15': 220uF; E2,5-6
C11: 330nF; C025-025X050
C16, C20: 1uF; E2,5-6
C17: 1uF; E2-4
CON1: USBSERIALSMD; USBSERIAL_SMD
D1: 1N4001; DO41-10
ESP-12: ESP-12; UZEBOX_ESP-12_TH
EXT: PINHD-2X8; 2X08
IC1: MCP1700; TO92-INLINE
IC2: 7805T; TO220H
JP1: JP2E; JP2
JP4, JP5: M05PTH; 1X05
KMDGX-9S-N: A/V; MINI-DIN-9
L1': 68uH; 6000-XXXX-RC
LED: LED; PINHEAD1X3
LED1: P607-ND; LED3MM
LED2: WS2812MINI; RGB3535
POWER: USER; TACTILE-PTH
R1, R22: 3.16K; 0207/10
R2, R12, R26, R27, R28: 301; 0207/10
R3, R6, R10, R18: 806; 0207/10
R4: 180; 0207/10
R5: 1.58K; 0207/10
R7, R11, R19, R20', R24', R25': 75; 0207/10
R8: 3.16k; 0207/10
R9, R17: 1.58k; 0207/10
R29, R30, R31: 562; 0207/10
RESET: RESET; TACTILE-PTH
SDCARD: SD_CARD_SOCKET4UCON; SDCARD_4UCONN
SJ1, SJ2, SJ3, SJ4, SJ5, SJ6: SJ
SJ7, SJ8: SJ2W; SJ_2
SNES_P1: SNES Player 1; SNES_CONNECTOR
SNES_P2: SNES Player 2; SNES_CONNECTOR
SV1: ISP; ML6L
U5: DC IN; PJ-102A
U6: 23LC1024; DIL08
VIDEO: RCA
XTAL: 28.63636Mhz; HC49/S

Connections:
+3V3: C17.+, C20.+, ESP-12.3 (CH_PD), ESP-12.8 (VCC), ESP-12.P$3 (CH_PD), ESP-12.P$8 (VCC), IC1.3 (OUT), SDCARD.4 (VDD)
+5V: A/V.7, AD725.1 (STND), AD725.4 (APOS), AD725.14 (DPOS), AD725.15 (VSYNC), ATMEGA644A-PU.10 (VCC), ATMEGA644A-PU.30 (AVCC), ATMEGA644A-PU.32 (AREF), C6'.1, C7'.1, C8'.+, C9'.+, C12.1, C13.1, C16.+, C19.1, CON1.P-5V (5V), EXT.15, IC1.2 (IN), IC2.3 (VO), JP4.1, JP5.1, LED.1, LED2.VSS (VCC), R4.2, R12.2, SNES_P1.P$8 (VCC), SNES_P2.P$8 (VCC), SV1.2, U6.7 (HOLD/SIO3), U6.8 (VCC)
AUDIO: A/V.8, AUDIO.SIG, KMDGX-9S-N.8, KMDGX-9S-N.9, R3.2, R22.1
B: A/V.6, C5'.1, KMDGX-9S-N.1, R17.2, R18.2, R19.1
BLUE: AD725.8 (BIN), C5'.2
BLUE1: ATMEGA644A-PU.28 ((TOSC1/PCINT22)PC6), R17.1
BLUE2: ATMEGA644A-PU.29 ((TOSC2/PCINT23)PC7), R18.1
CHROMA: KMDGX-9S-N.6, R24'.1
CVBS: JP1.3, R20'.2, VIDEO.SIG
CVBS/LUMA: JP1.2, KMDGX-9S-N.4
ESP_PROG: ATMEGA644A-PU.33 ((ADC7/PCINT7)PA7), ESP-12.12 (GPIO0), ESP-12.P$12 (GPIO0), EXT.9
ESP_RST: ATMEGA644A-PU.17 ((TXD1/INT1/PCINT27)PD3), ESP-12.1 (RESET), ESP-12.P$1 (RESET), EXT.11, SJ6.1, SJ8.1, SJ8.2
G: A/V.4, C4'.1, KMDGX-9S-N.3, R8.2, R9.2, R10.2, R11.1
GND: A/V.1, AD725.2 (AGND), AD725.13 (DGND), ATMEGA644A-PU.11 (GND), ATMEGA644A-PU.31 (GND), AUDIO.GND, C1.2, C2.2, C6'.2, C7'.2, C8'.-, C9'.-, C11.2, C12.2, C13.2, C16.-, C17.-, C18'.2, C19.2, C20.-, CON1.P-GND (GND), ESP-12.9 (GND), ESP-12.10 (GPIO15), ESP-12.P$9 (GND), ESP-12.P$10 (GPIO15), EXT.1, IC1.1 (GND), IC2.2 (GND), JP4.5, JP5.5, KMDGX-9S-N.G1, KMDGX-9S-N.G2, KMDGX-9S-N.G3, LED.3, LED1.K (C), LED2.VDD (GND), POWER.3, POWER.4, R3.1, R7.2, R11.2, R19.2, R29.1, R30.1, R31.1, RESET.3, RESET.4, SDCARD.3 (VSS1), SDCARD.6 (VSS2), SDCARD.SH@1 (SH), SDCARD.SH@2 (SH), SNES_P1.P$14 (GND), SNES_P2.P$14 (GND), SV1.6, U5.RING, U6.4 (GND), VIDEO.GND
GREEN: AD725.7 (GIN), C4'.2
GREEN0: ATMEGA644A-PU.25 ((TMS/PCINT19)PC3), R8.1
GREEN1: ATMEGA644A-PU.26 ((TDO/PCINT20)PC4), R9.1
GREEN2: ATMEGA644A-PU.27 ((TDI/PCINT21)PC5), R10.1
LUMA: JP1.1, R25'.1
MISO: ATMEGA644A-PU.7 ((MISO/PCINT14)PB6), ESP-12.7 (GPIO13), ESP-12.P$7 (GPIO13), EXT.2, SDCARD.7 (DAT0), SJ3.1, SJ3.2, SV1.1, U6.2 (SO/SIO1)
MOSI: ATMEGA644A-PU.6 ((MOSI/PCINT13)PB5), ESP-12.6 (GPIO12), ESP-12.P$6 (GPIO12), EXT.4, R28.2, SJ2.1, SJ2.2, SV1.4, U6.5 (SI/SIO0)
MOSI_3V3: R28.1, R31.2, SDCARD.2 (CMD)
unnamed: AD725.12 (YTRAP), L1'.1
unnamed: C18'.1, L1'.2
unnamed: CON1.P-TXO (TXO), SJ5.2
unnamed: CON1.P-RXI (RXI), SJ6.2
unnamed: LED.2, LED2.DOUT
unnamed: C10'.-, R20'.1
unnamed: AD725.10 (COMP), C10'.+
unnamed: ATMEGA644A-PU.12 (XTAL2), C1.1, XTAL.2
unnamed: D1.A, U5.TIP
unnamed: C14'.-, R24'.2
unnamed: ATMEGA644A-PU.13 (XTAL1), C2.1, XTAL.1
unnamed: ATMEGA644A-PU.21 ((OC2A/PCINT31)PD7), R22.2
unnamed: KMDGX-9S-N.2, R4.1
unnamed: C11.1, D1.C, IC2.1 (VI)
unnamed: ATMEGA644A-PU.18 ((XCK1/OC1B/PCINT28)PD4), LED2.DIN, R2.2
unnamed: LED1.A, R2.1
unnamed: C15'.-, R25'.2
unnamed: AD725.11 (LUMA), C15'.+
unnamed: AD725.9 (CRMA), C14'.+
PA5: ATMEGA644A-PU.35 ((ADC5/PCINT5)PA5), EXT.5, SJ7.3
PA6: ATMEGA644A-PU.34 ((ADC6/PCINT6)PA6), EXT.7, SJ8.3
PB1: ATMEGA644A-PU.2 ((CLKO/T1/PCINT9)PB1), EXT.14
PB2: ATMEGA644A-PU.3 ((INT2/AIN0/PCINT10)PB2), EXT.16
PD5: ATMEGA644A-PU.19 ((OC1A/PCINT29)PD5), EXT.13
POWER_SW: ATMEGA644A-PU.16 ((RXD1/INT0/PCINT26)PD2), POWER.1, POWER.2, SJ5.1, SJ7.1, SJ7.2
R: A/V.2, C3'.1, KMDGX-9S-N.7, R1.2, R5.2, R6.2, R7.1
RED: AD725.6 (RIN), C3'.2
RED0: ATMEGA644A-PU.22 ((SCL/PCINT16)PC0), R1.1
RED1: ATMEGA644A-PU.23 ((SDA/PCINT17)PC1), R5.1
RED2: ATMEGA644A-PU.24 ((TCK/PCINT18)PC2), R6.1
RESET: ATMEGA644A-PU.9 (!RESET), ESP-12.4 (GPIO16), ESP-12.P$4 (GPIO16), EXT.8, R12.1, RESET.1, RESET.2, SJ4.1, SJ4.2, SV1.5
SCK: ATMEGA644A-PU.8 ((SCK/PCINT15)PB7), ESP-12.5 (GPIO14), ESP-12.P$5 (GPIO14), EXT.6, R27.2, SJ1.1, SJ1.2, SV1.3, U6.6 (SCK)
SCK_3V3: R27.1, R30.2, SDCARD.5 (CLK)
SD_CE: ATMEGA644A-PU.20 ((OC2B/ICP/PCINT30)PD6), R26.2
SD_CE_3V3: R26.1, R29.2, SDCARD.1 (CD/DAT3)
SNES_CLK: ATMEGA644A-PU.37 ((ADC3/PCINT3)PA3), JP4.2, JP5.2, SNES_P1.P$9 (CLK), SNES_P2.P$9 (CLK)
SNES_DATA1: ATMEGA644A-PU.40 ((ADC0/PCINT0)PA0), JP4.4, SNES_P1.P$11 (DATA)
SNES_DATA2: ATMEGA644A-PU.39 ((ADC1/PCINT1)PA1), JP5.4, SNES_P2.P$11 (DATA)
SNES_LATCH: ATMEGA644A-PU.38 ((ADC2/PCINT2)PA2), JP4.3, JP5.3, SNES_P1.P$10 (LATCH), SNES_P2.P$10 (LATCH)
SPIRAM_EN: ATMEGA644A-PU.36 ((ADC4/PCINT4)PA4), EXT.3, U6.1 (!CS)
UART_RX: ATMEGA644A-PU.14 ((RXD0/PCINT24)PD0), ESP-12.16 (TXD), ESP-12.P$16 (TXD), EXT.10
UART_TX: ATMEGA644A-PU.15 ((TXD0/PCINT25)PD1), ESP-12.15 (RXD), ESP-12.P$15 (RXD), EXT.12
VIDEO_CE: AD725.5 (CE), ATMEGA644A-PU.5 ((OC0B/!SS!/PCINT12)PB4)
VIDEO_CLK: A/V.5, AD725.3 (4FSC), ATMEGA644A-PU.4 ((OC0A/AIN1/PCINT11)PB3)
VIDEO_SYNC: A/V.3, AD725.16 (HSYNC), ATMEGA644A-PU.1 ((XCK0/T0/PCINT8)PB0), KMDGX-9S-N.5

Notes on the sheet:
Optional Luma Trap
Alec Bourque
Copyright (c) Alec Bourque, Belogic
This work is free: you can redistribute it and/or modify
it under the terms of the GNU General Public License as published by
the Free Software Foundation, either version 3 of the License, or
(at your option) any later version.
This work is distributed in the hope that it will be useful,
but WITHOUT ANY WARRANTY; without even the implied warranty of
MERCHANTABILITY or FITNESS FOR A PARTICULAR PURPOSE. See the
GNU General Public License for more details.
You should have received a copy of the GNU General Public License
along with this work. If not, see <http://www.gnu.org/licenses/>.
Calibration print X=1.005
Video DAC design and SD voltage dividers contributed by Clay Cowgill.
Omega (PCB rev 1.1.1)
Optional Uzenet Interface
Added Mini-DIN SCART connector and some cleanup by Thorsten Erdmann (Bluescreen@trektech.de)
Option CVBS/sVideo Encoder
Option Wifi Interface
Option SPI RAM
Option USB interface

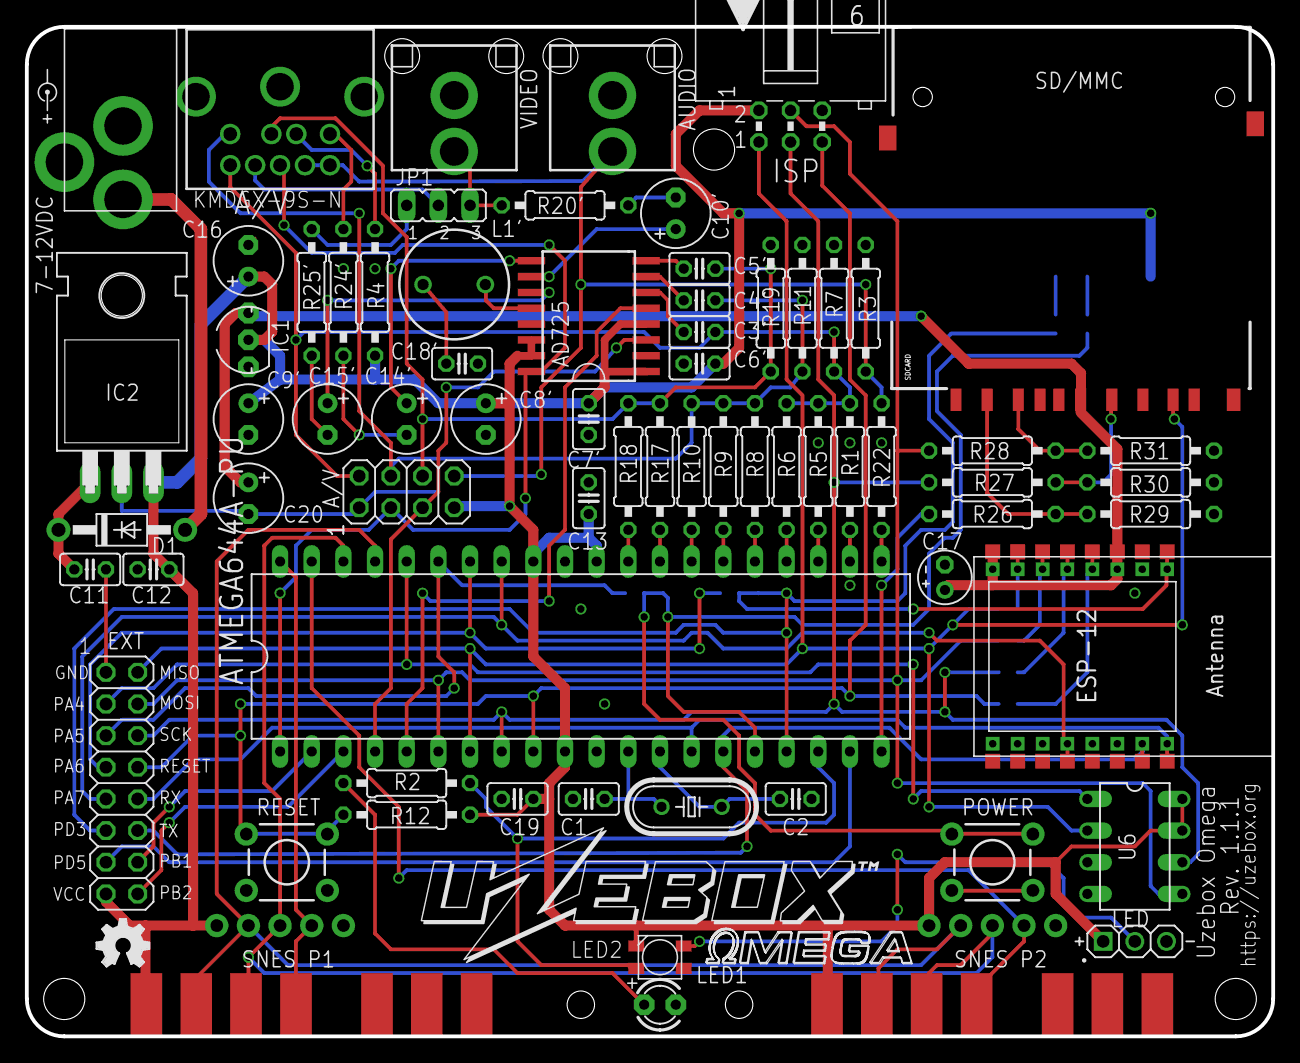
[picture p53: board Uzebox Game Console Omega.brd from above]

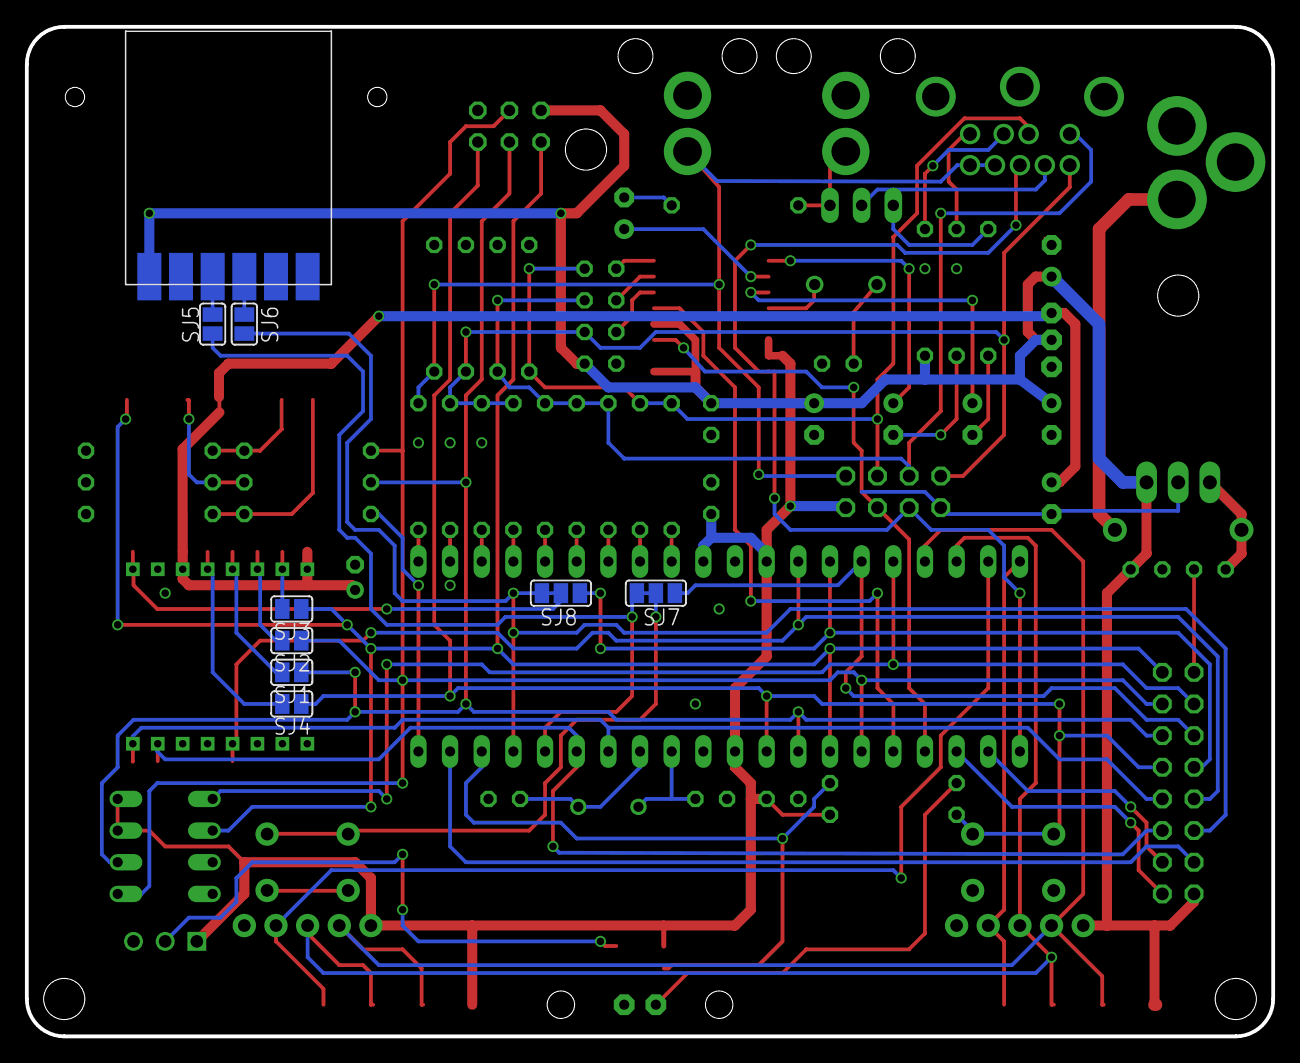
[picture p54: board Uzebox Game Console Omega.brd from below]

Board: 2 copper layers, 100.0 x 81.0 mm, 91 parts (9 on the bottom side), 67 nets.

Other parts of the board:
U$1: OSHW_FILLX150_NOTEXT
U$2, U$3, U$4: STAND-OFF
U$6: LOGO
U$7: POWER
U$8, U$9, U$10, U$11: BUMPON

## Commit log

2025-06-29 Add Uzebox Omega v1.1.1 files
    [Uzebox Game Console Omega.brd, Uzebox Game Console Omega.sch]
2025-06-29 Fix PCB image link
2025-07-06 Add BOM files
    [Uzebox-Omega-1.1.1-BOM-DigiKey.xlsx, Uzebox-Omega-1.1.1-BOM-Farnell.xlsx]
2025-07-10 Use dir structure of Uzebox repo and change ISP header for both BOMs
    [Uzebox Game Console Omega.brd, Uzebox Game Console Omega.sch, Uzebox-Omega-1.1.1-BOM-DigiKey.xlsx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]
2025-07-10 Remove old files from repo root dir
    [Uzebox Game Console Omega.brd, Uzebox Game Console Omega.sch, Uzebox-Omega-1.1.1-BOM-DigiKey.xlsx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]
2025-07-10 Add text BOM file
2025-07-10 Add video fix resistor and multi-plug power adapter to text BOM
2025-07-10 Add PCB photo
2025-07-10 Add alternate part numbers for ISP sockets to both BOMs
    [Uzebox-Omega-1.1.1-BOM-DigiKey.xlsx, Uzebox-Omega-1.1.1-BOM-Farnell.xlsx]
2025-07-10 Add a 9V internatioal PSU to the text BOM
2025-07-11 Add the Uzebox assembly guide and its assets
2025-07-11 Add small PCB photo - image66.png
2025-07-11 Update PCB description
2025-07-11 Improve PCB description
2025-07-11 Replace S-Video with 9 pin mini DIN socket in the components list
2025-07-11 Replace composite cable pic with Mega Drive 2 SCART cable pic
2025-07-11 Fix Mega Drive 2 SCART cable pic file type
2025-07-11 Update solder flux comment to remove AD725
2025-07-11 Remove AD725 soldering section
2025-07-11 the 40 pin DIP socket is marked on the silkscreen as MCU
2025-07-11 Improve SCART cable description
2025-07-11 Cable label 2.GO
2025-07-11 Start the Building the kit section by recommending soldering the power jack first
2025-07-11 Improve power jack section
2025-07-11 Further improve power jack section
2025-07-11 Move soldering of DC jack section to step 2
2025-07-11 Move most of the reasoning for soldering the DC jack first to step 2
2025-07-12 Update guide note to add disclaimer for differing PCB revisions used in guides photos
2025-07-12 Add alternate method of inserting the regulator
2025-07-12 (Re)add C12 to BOMs
    [Uzebox-Omega-1.1.1-BOM-DigiKey.xlsx, Uzebox-Omega-1.1.1-BOM-Farnell.xlsx]
2025-07-12 Add wire cutting safety tips
2025-07-12 The current DigiKey BOM uses 1uF caps that are dark blue so update their description
2025-07-12 Add tips for fixing a Uzebox not giving a correct voltage measurement after soldering the power circuit
2025-07-12 Edit solder tips
2025-07-13 Replace first image in Assembling the microcontroller and sound section with an Omega image, add ISP header here
2025-07-13 Replace Video DAC image with Omega PCB equivalent
2025-07-13 Replace Assemble the video section images with Omega PCB equivalents
2025-07-13 Edit Assemble the video section
2025-07-13 Remove 75R resistors from parts list, only 4x .10UF 50V caps required
    [Uzebox-Omega-1.1.1-BOM-DigiKey.xlsx, Uzebox-Omega-1.1.1-BOM-Farnell.xlsx]
2025-07-14 Recommend using a fine soldering iron tip when soldering the SD card socket
2025-07-14 Add tips for soldering the SD card socket
2025-07-14 Update SD card socket image with Omega version
2025-07-14 Update second SD card socket image with Omega version
2025-07-15 Omegify SNES connectors section
2025-07-15 Add 8 position DIP socket for SPI RAM to parts list
2025-07-15 Add SPI SRAM to parts list
2025-07-16 Add image of fully soldered Omega PCB
2025-07-16 Actually add image of fully soldered Omega PCB
2025-07-16 Update README. Add Assembly Guide link
2025-07-16 Update PCB image used by README
2025-07-18 Add Uzebox case method of soldering SNES connectors
2025-07-22 Move link for SCART to HDMI converters to 'Assembling the video section'
2025-07-23 Add Uzebox fightstick CAD files
    [Fight Stick Uzebox Edition v7.step, Fightstick Bottom V3 30mm.stl]
2025-08-12 Add pic of video sync fix resistor
2025-08-12 Add links to recommended SCART cables and SCART to HDMI converters
2025-08-14 Add more resistor info for video fix
2025-08-17 Add Fightstick README and wiring pics
2025-08-17 Edit Fightstick BOM
2025-08-17 Add written instructions for the wiring section of the README
2025-08-17 Add joystick photo and update wiring pic
2025-08-18 Add Uzebox controller PCB to Fightstick BOM
2025-08-19 Add suggested button layout pic
2025-09-03 Update Digikey BOM comments
    [Uzebox-Omega-1.1.1-BOM-DigiKey.xlsx]
2025-09-05 Add SPI RAM and socket to DigiKey BOM
    [Uzebox-Omega-1.1.1-BOM-DigiKey.xlsx]
2025-10-30 Update README Omega PCB photo
2025-10-30 Add photo of the recommended way to solder the SNES connectors, within the Uzebox case
2025-10-30 Replace SNES connector soldering image
2025-10-30 Add link to the Omega's PCBWay shared project page
2025-11-15 Add Uzenet header components to text BOM
2025-11-28 Update schematic
    [Uzebox Game Console Omega.brd, Uzebox Game Console Omega.sch]
2026-02-12 Update BOMs to replace voltage regulator
    [Uzebox-Omega-1.1.1-BOM-DigiKey.xlsx]
2026-03-30 Fix link to seller of 180 degree SNES connectors
2026-04-26 Revert voltage regulator
    [Uzebox-Omega-1.1.1-BOM-DigiKey.xlsx]
2026-08-09 Change mini DIN socket part for DigiKey BOM
    [Uzebox-Omega-1.1.1-BOM-DigiKey.xlsx]
2026-08-23 Add .pdf version of assembly guide
2026-08-24 Add page numbers to pdf version of assembly guide
2026-08-27 Improve formatting of assembly guide

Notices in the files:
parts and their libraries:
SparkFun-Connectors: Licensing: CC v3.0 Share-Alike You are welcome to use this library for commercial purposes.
